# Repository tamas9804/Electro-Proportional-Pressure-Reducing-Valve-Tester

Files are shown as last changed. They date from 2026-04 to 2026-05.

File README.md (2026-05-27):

# Elektronikus nyomáscsökkentő szelep tesztelő

## Megvalósítandó funkciók

### 1. Mérési funkciók 
* **Szelepek folytonosságának mérése:** Gyors szakadás- és zárlatvizsgálat a szelepek tekercsén.
* **Nagy pontosságú ellenállásmérés:** A szelepek tekercsellenállásának precíziós mérése **0,1%-os pontossággal**, ami lehetővé teszi a minimális menetzárlatok vagy degradációk kiszűrését is.
* **Többcsatornás architektúra:** A rendszernek alkalmasnak kell lennie egyszerre két szelep fogadására és mérésére/tesztelésére.

### 2. Vezérlési és hajtás funkciók 
* **Teljes kivezérlés:** A szelepek direkt, folyamatos (100%-os) kivezérlése a maximális elmozdulás és működés ellenőrzéséhez.
* **PWM kivezérlés:** Impulzusszélesség-modulált (PWM) jel biztosítása a proporcionális szelepek áram- és nyomásszabályzási karakterisztikájának teszteléséhez.
* **Polaritásváltás (H-híd konfiguráció):** A hardvernek felkészültnek kell lennie a polaritás szoftveres felcserélésére, biztosítva a jövőbeli kompatibilitást a többállású vagy irányváltó szelepekkel.

### 3. Hardver és elektromos védelem 
* **Széles tápfeszültség-tartomány:** Az áramkörnek stabilan kell üzemelnie **12V és 24V DC** közötti betáplálási feszültségen, alkalmazkodva az ipari és járműipari szabványokhoz.
* **Fordított polaritás elleni védelem:** Védelem a tápvezetékek téves felcserélése ellen a belső elektronika megóvása érdekében.
* **Túláramvédelem:** A fő tápágat egy **10A-es biztosíték** védi a zárlatokból vagy túlterhelésekből adódó károk ellen.

### 4. Felhasználói felület és szoftver 
* **Beépített menürendszer:** A műszernek rendelkeznie kell egy lokális kijelzőn és fizikai nyomógombokon keresztül kezelhető, jól strukturált menürendszerrel. A szoftvernek kötelezően biztosítania kell az alábbi dedikált menüpontokat:
  * **Teljes teszt:** Egy automatizált tesztszekvencia, amely felhasználói beavatkozás nélkül, egymás után elvégzi a szakadásvizsgálatot, az ellenállásmérést, és végül teljesen kivezérli a szelepet.
  * **Szakadásvizsgálat:** Külön menüpont a tekercs folytonosságának gyors és célzott ellenőrzésére.
  * **Ellenállásmérés:** Dedikált funkció a szelep tekercsellenállásának precíziós mérésére.
  * **Teljes kivezérlés:** A szelep 100%-os, folyamatos statikus meghajtása az azonnali működés-ellenőrzéshez.
  * **PWM kivezérlés:** Impulzusszélesség-modulált (PWM) jel kiadása a szelep proporcionális mozgásának teszteléséhez.
  * **Beállítások:** Rendszerkonfigurációs menü, ahol a felhasználó megadhatja a tesztelt szelepek számát, illetve kiválaszthatja a kívánt nyelvet.
* **Többnyelvűség:** A szoftver képesnek kell lennie több nyelv (Magyar, Angol, Német) dinamikus kezelésére és tartós tárolására.A műszernek újraindítás után is megkell jegyeznie az elmentett szelepek számát, illetve a beállított nyelvet

##  Kiválasztott hardverkomponensek 

A projekt áramköri kialakítása során a fő szempont a megbízhatóság, a költséghatékonyság, valamint az ipari (12-24V) környezetnek való megfelelés volt. Az áramkör az alábbi főbb alkatrészekre épül:

### 1 Vezérlés és Megjelenítés
* **Arduino Nano (ATmega328P):** Költséghatékony, könnyen programozható, és az I/O lábszáma, valamint a számítási kapacitása tökéletesen elegendő a műszer funkcióinak (állapotgép, I2C kommunikáció, PWM) ellátására.
* **16x4 LCD kijelző (I2C modullal):** A teszteredmények és a menürendszer megjelenítéséért felel. Az I2C bővítőnek köszönhetően mindössze két adatvonalat (SDA, SCL) igényel, így rengeteg portot spórol meg a mikrokontrolleren, és a programozása is rendkívül egyszerű.
### 2 Precíziós Mérésadatgyűjtés
* **ADS1115 (16-bites ADC):** A mikrokontroller beépített, alacsonyabb felbontású analóg-digitális átalakítója helyett ez a dedikált IC garantálja a rendkívül pontos (akár 0,1%-os) áram- és feszültségmérést.
* **LM317 feszültségszabályzó (Áramgenerátoros módban):** A precíziós ellenállásmérés alapja. Stabil, állandó mérőáramot biztosít a szelepek tekercsére, ami elengedhetetlen a pontos ellenállás kiszámításához.
* **Feszültségosztó hálózat:** Egy dedikált, egyszerű és gyors mérőáramkör a tekercsek folytonosságának azonnali ellenőrzésére.
### 3. Teljesítményvezérlés és Tápellátás
* **LM2596S DC-DC Step-down konverter:** A műszer tápegysége. A széles ipari feszültségtartományt (12V - 24V) hatékonyan és biztonságosan alakítja át a logikai áramkörök számára szükséges 5V-os stabil feszültségre.
* **AOD409 (P-csat) és IRLR2705 (N-csat) MOSFET-ek:** Ezek a nagy áramtűrésű tranzisztorok felelnek a szelepek (H-híd topológiájú) meghajtásáért. Biztosítják a biztonságos, melegedésmentes PWM szabályozást és a folyamatos, 100%-os kivezérlést a legnagyobb áramfelvételű szelepek esetén is.
* **SRD-05VDC-SL-C 5V Relék:** Mechanikus kapcsolóelemek, amelyek a különböző mérési körök (pl. áramgenerátoros mérés és PWM hajtás) fizikai és galvanikus leválasztását végzik, védve ezzel az érzékeny mérőelektronikát a tesztelés során.
### 4. Mechanika és Csatlakozók
* **JST XH csatlakozók a PCB-n:** A kijelző, a nyomógombok és a potenciométerek nem közvetlenül a panelre vannak forrasztva, hanem szabványos XH csatlakozókkal csatlakoznak. Ez drasztikusan megkönnyíti az alkatrészek cseréjét, valamint sokkal nagyobb szabadságot ad a végleges műszerház (enclosure) 3D tervezésénél és összeszerelésénél

## Részletes Áramköri Felépítés

Mivel a teljes kapcsolási rajz A3-as méretű, a könnyebb átláthatóság és olvashatóság érdekében funkcionális blokkokra bontva mutatjuk be a hardver működését.

A teljes rajz letölthető [**PDF formátumban**](Hardware/EPPR_tester_full.pdf)

### 1. Tápellátás és Fordított Polaritás Elleni Védelem
Ez a modul felel a rendszer stabil feszültségellátásáért. A 24V-os bemenetet egy biztosíték és egy dióda védi a fordított polaritás ellen. Egy **LM2596S** kapcsolóüzemű szabályzó állítja elő a logikai áramkörök számára szükséges stabil 5V-ot nagy hatásfokkal.

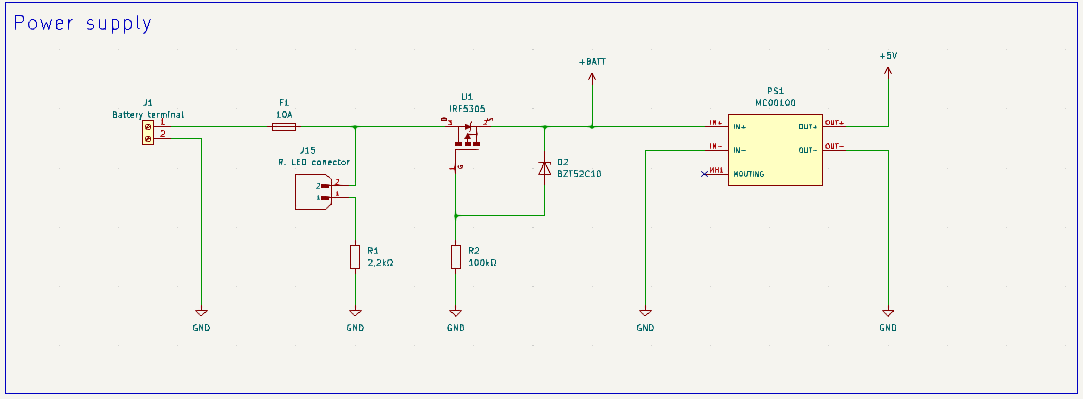
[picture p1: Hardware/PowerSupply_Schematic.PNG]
Tápellátás


### 2. Vezérlő interfészek és Felhasználói Felület csatlakozók
Itt látható az **Arduino Nano** mikrokontroller központi bekötése. Ez a modul kezeli az I2C buszt az LCD kijelzőt és az ADC-t. Tartalmazza a JST XH csatlakozók bekötését a navigációs nyomógombokhoz, a potméterhez.

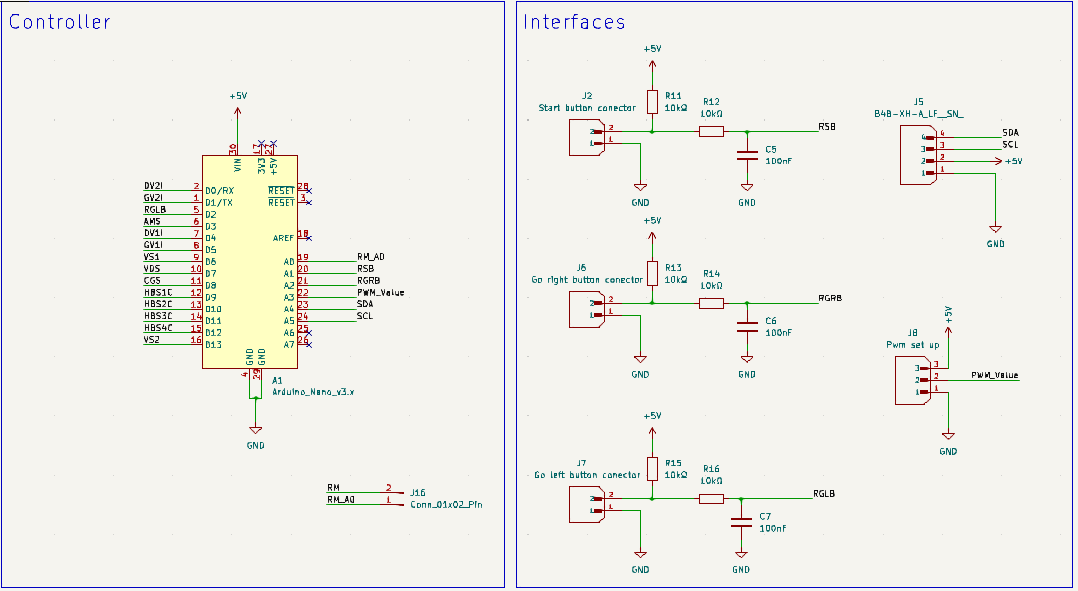
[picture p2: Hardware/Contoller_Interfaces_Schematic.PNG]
Vezérlő


#### 3. Precíziós Analóg-Digitális Átalakítás 
A nagy pontosságú mérésekért egy **ADS1115** 16-bites külső ADC modul felel. I2C buszon kommunikál a vezérlővel.

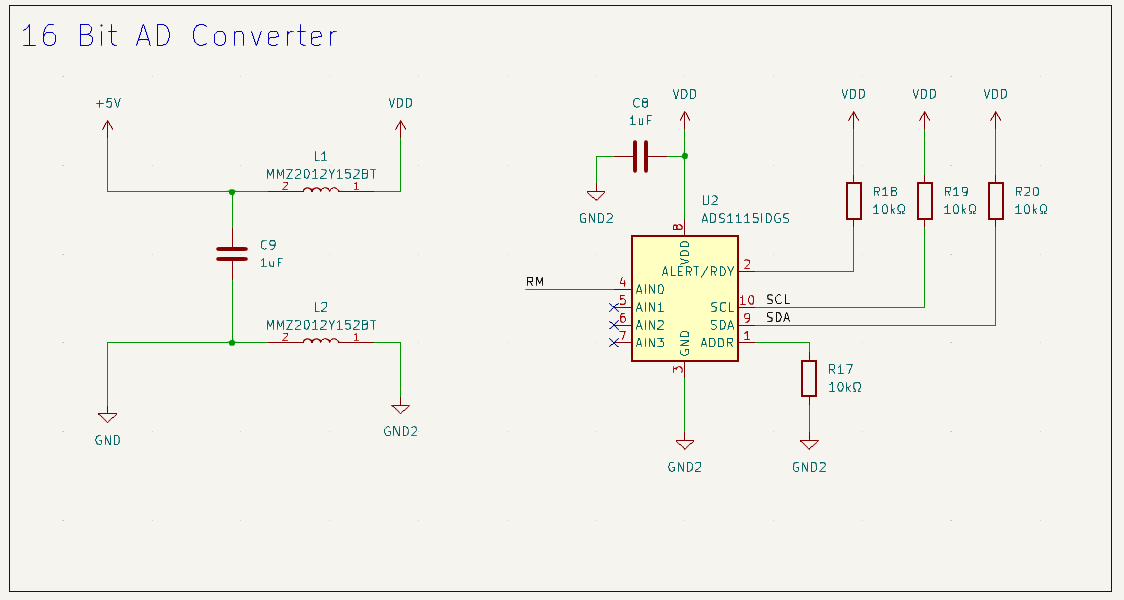
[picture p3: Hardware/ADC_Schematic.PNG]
ADC modul


### 4 Polaritás váltó híd 
Ez az áramkör tartalmazza a polaritás váltást az adott kimeneten, illetve kezeli hogy 12V illetve 24V-ről is tudjon működni.

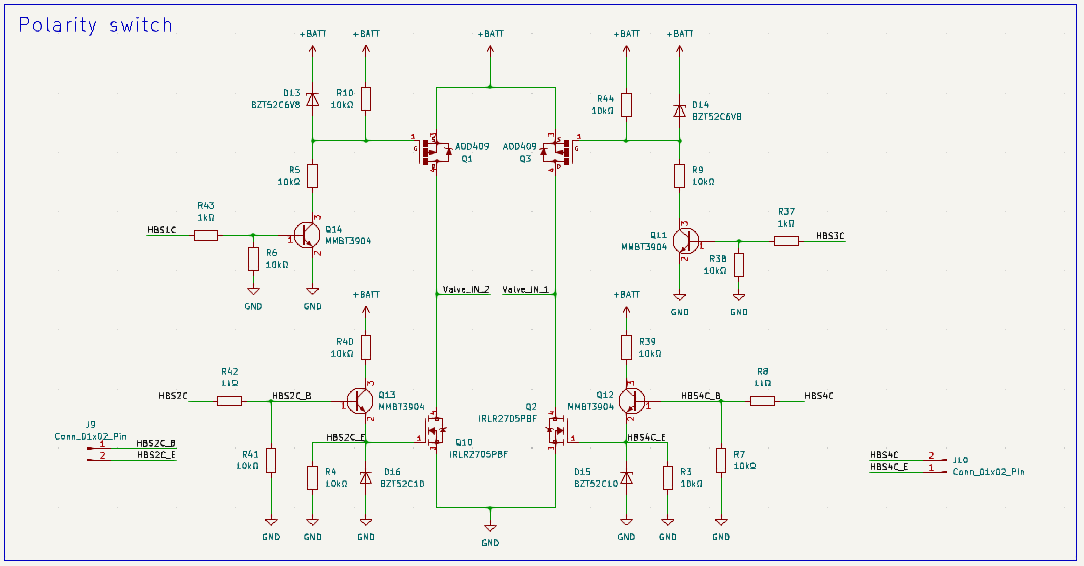
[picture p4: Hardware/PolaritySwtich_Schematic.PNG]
Funkcióváltó


### 5 Mérési Mód Választó Relé 
Ez a modul választja ki, hogy az ADC éppen az analóg mérőjelet vagy a folytonossági teszthez szükséges feszültségosztót olvassa be.

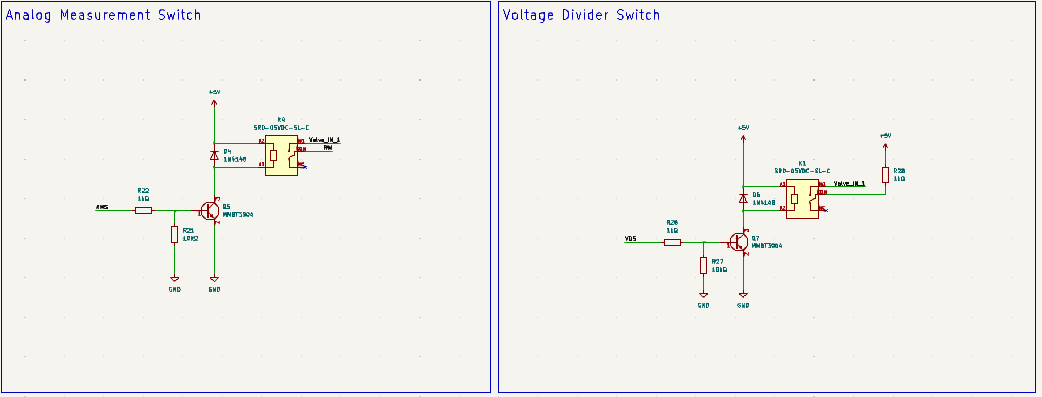
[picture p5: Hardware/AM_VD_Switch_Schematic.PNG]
Mérési mód választó


### 6 Szelep Szekvencia Választó Relék
Ez a rész kapcsolja a kimenetet, ezzel a kapcsolással egyszerre két szelep is rácsatlakoztatható és külön külön lemérhető.

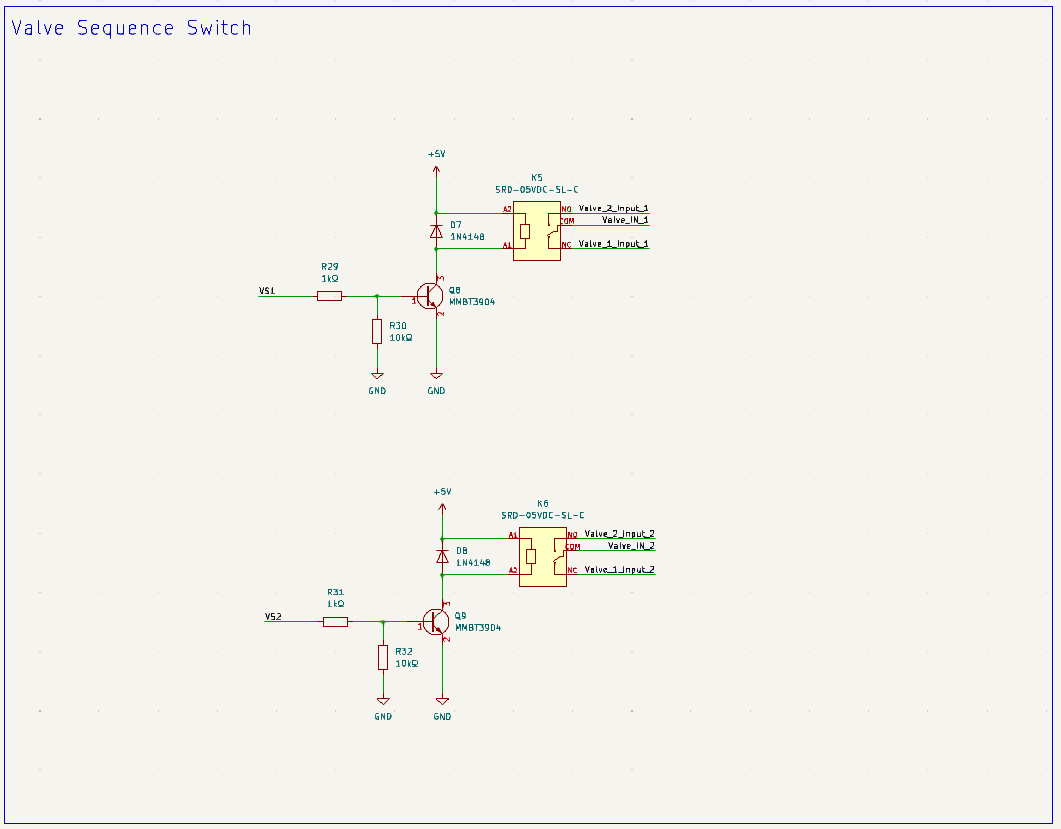
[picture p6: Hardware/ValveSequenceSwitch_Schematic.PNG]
Szelep választó


### 7 Szelep Csatlakozók és Állapotjelző LED-ek
Ez a kimeneti modul tartalmazza a fizikai sorkapcsokat a szelepek bekötéséhez. Tartalmazza az optikai visszajelzést biztosító LED csatlakozását amelyek mutatják az adott szelep kimenet állapotát.

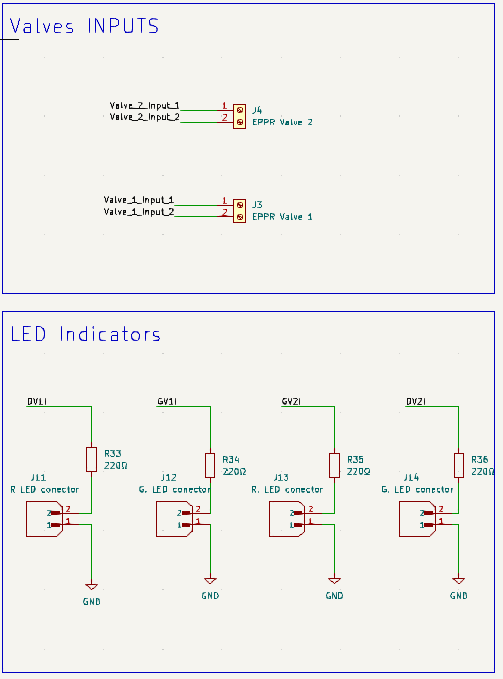
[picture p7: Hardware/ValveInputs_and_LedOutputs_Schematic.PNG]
Szelep kimenetek


## Nyomtatott Áramkör 

A megbízható és zajmentes ipari működés érdekében a NYÁK-tervezés során az alábbi tervezési irányelveket követtem:

* **4 rétegű felépítés:** A panel ipari szabványú **FR-4**-es hordozóanyagra készült, 4 rétegű kialakítással. Ez lehetővé tette a jelvezetékek és a tápvezetékek optimális szétválasztását.
* **Dedikált Föld és Táp síkok:** A kiváló zajvédelem érdekében a két belső réteg dedikált feladatot kapott. Az egyik egy megszakítás nélküli, masszív Föld-sík, a másik pedig egy egybefüggő Táp-sík (5V). Ez minimalizálja a hurok-induktivitást és stabil referenciát biztosít a precíziós analóg mérésekhez.
* **Áramra méretezett vezetősávok:** A teljesítményelektronikai részeknél a vezetősávok szélessége a maximális átfolyó áramra lett méretezve a melegedés és a feszültségesés elkerülése végett.
* **Zajszűrés optimalizálása:** A tápszűrő kondenzátorok fizikailag a lehető legközelebb kerültek az integrált áramkörök (Arduino Nano, ADS1115, LM317) táplábaihoz, így hatékonyan nyelik el a magas frekvenciás tranzienseket.
* **Adatvonalak árnyékolása:** A kritikus kommunikációs vonalak (például az I2C busz SDA és SCL vonalai) a rézrétegen mindkét oldalról föld-sávokkal lettek körbevéve. Ez a technika drasztikusan csökkenti az áthallást és megvédi az érzékeny digitális jeleket a relék által keltett zavaroktól.
* **Precíziós Analóg Tápszűrés:** Az **ADS1115** 16-bites ADC tápellátását egy dedikált ferrit szűrővel választottuk le a közös 5V-os digitális tápvezetékről. Ez a szűrőmegoldás hatékonyan blokkolja a mikrokontroller és a digitális kapcsolóelemek által keltett nagyfrekvenciás zajokat, így garantálja a zajmentes tápfeszültséget az ADC számára, ami elengedhetetlen a 0,1%-os mérési pontosság eléréséhez.

## 3D Modell

A nyomtatott áramkörről és a rászerelt alkatrészekről egy teljes 3D modell készült. Ez a modell alapvető fontosságú a műszer külső dobozolásának megtervezéséhez, az ütközések ellenőrzéséhez, valamint a gombok és a kijelző pontos pozicionálásához.

**A PCB 3D-s látványterve :**
[**Kattints ide a panel interaktív 3D megtekintéséhez!**](Hardware/3D%20file/EPPR%20tester.stl)

## Fizikai Összeépítés és Prototípus

Az alábbi képen a már legyártott, 4 rétegű **FR-4**-es nyomtatott áramkör látható a valóságban, készre szerelt állapotban. 

**A kész, működőképes áramkör a valóságban:**
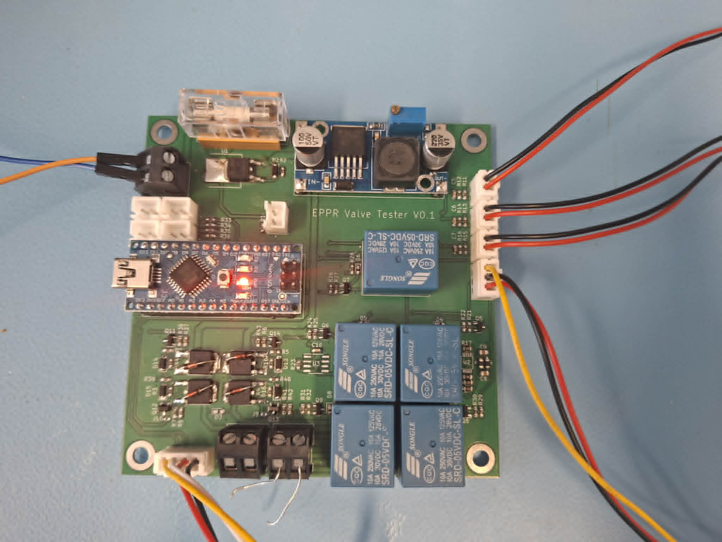
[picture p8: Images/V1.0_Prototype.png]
Fizikai összeépítés


## Szoftver Architektúra és Kódolási Irányelvek 

A beágyazott szoftver **C++ nyelven**, az Arduino keretrendszerre támaszkodva íródott. A kódolás során a fő szempont a megbízhatóság, a mikrokontroller szűkös erőforrásainak optimalizálása, valamint a méréstechnikai pontosság maximalizálása volt.

A fejlesztés során az alábbi kulcsfontosságú programozási technikákat alkalmaztuk:

### 1. Véges Állapotgép 
A szoftver működése egy robusztus, többszintű állapotgépre épül. Az állapotokat (Főmenü, Beállítások, Tesztelési folyamatok) `enum class` struktúrák vezérlik (`SystemMode`, `MenuStates`, `SettingStates`).
* **Előny:** Ez a megközelítés teljesen kiküszöböli az átláthatatlan kódot, és a `loop()` függvényt könnyen bővíthetővé teszi, elkerülve a blokkoló várakozásokat.

### 2. Memóriaoptimalizálás és Többnyelvűség
A műszer három nyelvet támogat (Magyar, Angol, Német). Mivel a kijelzőn megjelenő stringek gyorsan kimerítenék az Arduino Nano (ATmega328P) mindössze 2 kByte-os SRAM memóriáját, az összes szöveges konstans a **Flash memóriában (`PROGMEM`)** kapott helyet.
* **Megvalósítás:** Egy dedikált lekérdező függvény (`getText()`) olvassa ki a kért nyelvi elemeket futásidőben a Flash memóriából egy rövid bufferbe, drasztikusan csökkentve a futásidejű memóriafoglalást.

#### 3. Szoftveres Zajszűrés és Dinamikus Felbontás
A 0,1%-os pontosságú mérés érdekében a hardveres szűrés mellett speciális szoftveres eljárásokat is bevezettem:
* **Túlmintavételezés:** Az analóg értékek beolvasásakor a kód ciklusonként 100 mintát vesz, és ezek átlagolásával (`getAveragedVoltage()`) szűri ki a hálózati és kapcsolási zajokat.
* **Dinamikus Erősítés:** Az ellenállásmérés (`OhmTest`) során a szoftver az ADS1115-ös IC beépített programozható erősítőjét (PGA) dinamikusan állítja (`GAIN_EIGHT`, `GAIN_FOUR`, stb.). Ha a mért feszültség túl alacsony, a rendszer automatikusan nagyobb erősítésre kapcsol, így mindig kihasználja a 16-bites felbontás maximumát a különböző ellenállás-tartományokban.

#### 4. EEPROM Kezelés és "First Start" Detektálás
A felhasználói beállítások (kiválasztott nyelv, szelepek száma) a nem felejtő **EEPROM** memóriában tárolódnak.
* **Intelligens inicializálás:** A szoftver tartalmaz egy `doFirstStart()` logikát, amely egy specifikus azonosító (Magic Number: `78`) keresésével megállapítja, hogy a mikrokontroller most lett-e először felprogramozva. Ha igen, automatikusan feltölti az EEPROM-ot az alapértelmezett gyári értékekkel, megelőzve a memóriaszemétből adódó összeomlásokat.

#### 5. Hardveres Védelem és Tiszta Újraindítás
* A tesztelési fázisok indításakor és leállításakor a szoftver szigorú sorrendben kapcsolja a hardveres reléket és a PWM jeleket, hogy elkerülje a mérőáramkör túlterhelését.
* A beállítások mentése után a rendszer nem szoftveres trükkökkel, hanem a hardveres **Watchdog Timer (`wdt_enable`)** szándékos lejáratásával (`softwareReset()`) hajt végre egy teljesen tiszta újraindítást, garantálva, hogy minden regiszter és memóriacím az alapállapotba kerüljön.

## Javítási és Továbbfejlesztési Tervek 

Bár a műszer prototípusa teljesen működőképes és ellátja az alapvető mérési funkciókat, a jövőbeli verziókhoz az alábbi javítások lehetőségesek:

### Szoftveres javítások és optimalizálás (Known Issues & Fixes)
* **PWM Teszt implementálása:** A menürendszerben már szerepel, de a `PwmTest()` funkció logikája (a hardveres időzítők és a kitöltési tényező dinamikus állítása) még megírásra vár.
* **Blokkoló kódok kiváltása:** A tesztelési folyamatok végén jelenleg `delay(4000)` található. Ezt a jövőben `millis()` alapú, nem blokkoló időzítésre cseréljük, hogy a műszer közben reagálhasson a gombnyomásokra.
* **Kalibrációs menü:** Egy rejtett menüpont létrehozása, ahol az áramgenerátor és a feszültségosztó pontatlanságait szoftveresen (Offset és Gain értékekkel) lehet kalibrálni és az EEPROM-ba menteni.

### Hardveres és Rendszerszintű továbbfejlesztések
* **Induktív visszarúgás elleni védelem:** A jelenlegi V1.0-s nyomtatott áramkörről lemaradtak a szelepek (induktív terhelések) kikapcsolásakor keletkező feszültségtüskék elleni védődiódák. A működő prototípuson ezt ideiglenesen utólagos ráforrasztással oldottuk meg. A következő PCB terv frissítésnél ezek a Schottky védődiódák dedikált helyet és megfelelő hűtőfelületet kapnak a H-híd kimeneteinél, garantálva a MOSFET-ek hosszú távú védelmét.
* **Adatnaplózás (Data Logging):** Egy MicroSD kártya modul integrálása az I2C/SPI buszra, hogy a teszteredményeket .CSV formátumban el lehessen menteni a későbbi elemzéshez.
* **PC-s kommunikáció (Serial Plotter):** A tesztelés alatti áram- és feszültséggörbék (különösen a PWM kivezérlés esetén) folyamatos küldése USB-n keresztül egy PC-s szoftvernek, vizuális grafikonrajzolás céljából.

### Karbantartás és Fizikai javítás 
A hardver úgy lett megtervezve, hogy a terepi javítás a lehető legegyszerűbb legyen:
* **Relék és Csatlakozók:** A mechanikus kopásnak kitett alkatrészek (SRD relék), egy esetleges beégés esetén könnyen kicseréhetővé tétele

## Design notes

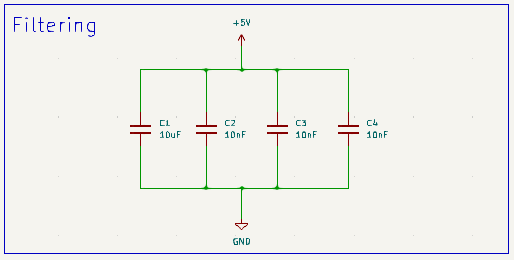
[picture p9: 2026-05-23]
Hardware/Filtering_Schematic.PNG

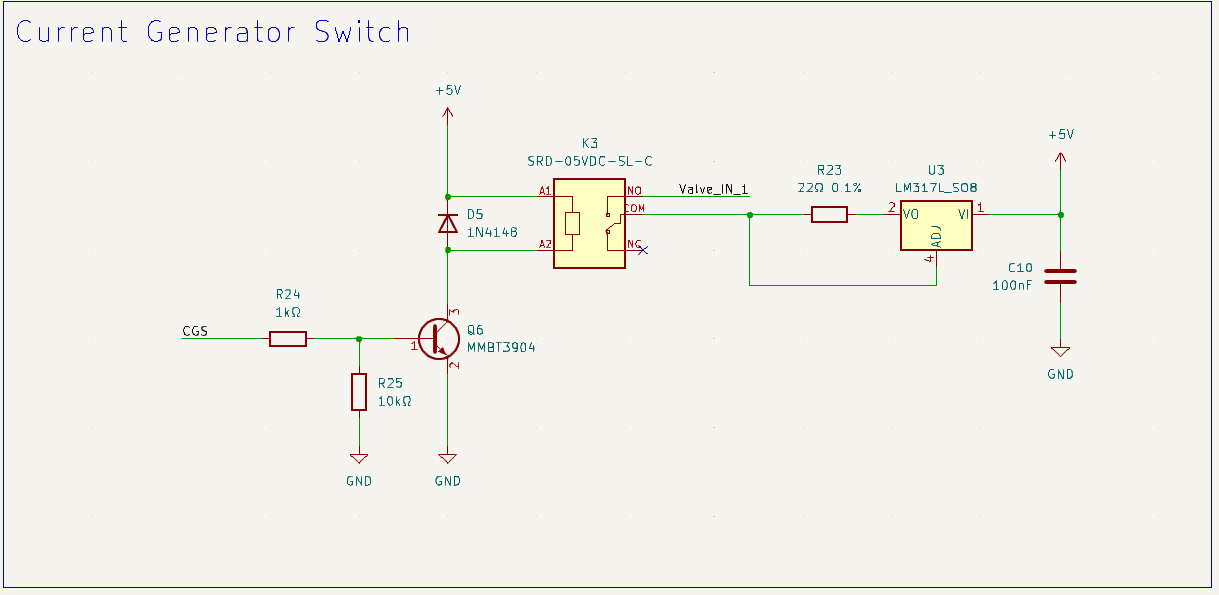
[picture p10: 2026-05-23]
Hardware/CurrentGenerator_Schematic.PNG

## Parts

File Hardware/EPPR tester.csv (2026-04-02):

Column1 | Column2 | Column3 | Column4 | Column5 | Column6 | Column7 | Column8 | Column9 | Column10 | Column11 | Column12 | Column13 | Column14 | Column15 | Column16 | Column17 | Column18 | Column19 | Column20 | Column21 | Column22 | Column23 | Column24 | Column25 | Column26 | Column27 | Column28
Source: | C:\Users\molnart1\Desktop\Vezérlő projekt\EPPR tester\EPPR tester\EPPR tester.kicad_sch
Date: | 2026. 03. 27. 14:00:19
Tool: | Eeschema 7.0.9
Generator: | C:\Program Files\KiCad\7.0\bin\scripting\plugins/bom_csv_grouped_by_value.py
Component Count: | 107
Collated Components:
Item | Qty | Reference(s) | Value | LibPart | Footprint | Datasheet | DNP | Availability | CREATOR | Check_prices | Description | MANUFACTURER | MAXIMUM_PACKAGE_HEIGHT | MF | MP | Manufacturer_Name | Manufacturer_Part_Number | PARTREV | Package | Price | SMD/THT | STANDARD | Sim.Device | Sim.Pins | SnapEDA_Link | Third Party Seller 1 | Website
1 | 1 | A1 | Arduino_Nano_v3.x | MCU_Module:Arduino_Nano_v3.x | Module:Arduino_Nano | http://www.mouser.com/pdfdocs/Gravitech_Arduino_Nano3_0.pdf
2 | 1 | C1 | 10uF | Device:C | Capacitor_SMD:C_1210_3225Metric_Pad1.33x2.70mm_HandSolder | ~
3 | 3 | C2, C3, C4 | 10nF | Device:C | Capacitor_SMD:C_0603_1608Metric_Pad1.08x0.95mm_HandSolder | ~
4 | 4 | C5, C6, C7, C10 | 100nF | Device:C | Capacitor_SMD:C_0603_1608Metric_Pad1.08x0.95mm_HandSolder | ~
5 | 2 | C8, C9 | 1uF | Device:C | Capacitor_SMD:C_0603_1608Metric_Pad1.08x0.95mm_HandSolder | ~
6 | 3 | D2, D15, D16 | BZT52C10 | Device:D_Zener | Diode_SMD:Nexperia_CFP3_SOD-123W | ~
7 | 6 | D3, D4, D5, D6, D7, D8 | 1N4148 | Diode:1N4148 | Diode_SMD:D_0603_1608Metric_Pad1.05x0.95mm_HandSolder | https://www.tme.eu/Document/8a0f4bd1d0e0495ebb1834ba060fbfa0/CD4148.pdf |  |  |  |  |  |  |  |  |  | DC COMPONENTS | CD4148WT(0603C) |  | 0603 |  | SMD |  | D | 1=K 2=A |  | https://www.tme.eu/hu/details/1n4148-0603/univerzalis-smd-diodak/dc-components/cd4148wt-0603c/ | -
8 | 2 | D13, D14 | BZT52C6V8 | Device:D_Zener | Diode_SMD:Nexperia_CFP3_SOD-123W | ~
9 | 1 | F1 | 15A | Device:Fuse | Fuse:Fuseholder_Littelfuse_100_series_5x20mm | ~
10 | 1 | J1 | Battery terminal | Connector:Screw_Terminal_01x02 | TerminalBlock:TerminalBlock_Altech_AK300-2_P5.00mm | ~
11 | 1 | J2 | Start button conector | B2B-XH-A:B2B-XH-A | B2B-XH-A:JST_B2B-XH-A |  |  | In Stock |  | https://www.snapeda.com/parts/B2B-XH-A/JST/view-part/?ref=eda | Connector Header Through Hole 2 position 0.098 (2.50mm) | JST Sales America Inc. | 7 mm | JST Sales | B2B-XH-A |  |  | N/A | None | None |  | Manufacturer Recommendations |  |  | https://www.snapeda.com/parts/B2B-XH-A/JST/view-part/?ref=snap
12 | 1 | J3 | EPPR Valve 1 | Connector:Screw_Terminal_01x02 | TerminalBlock:TerminalBlock_Altech_AK300-2_P5.00mm | ~
13 | 1 | J4 | EPPR Valve 2 | Connector:Screw_Terminal_01x02 | TerminalBlock:TerminalBlock_Altech_AK300-2_P5.00mm | ~
14 | 1 | J5 | B4B-XH-A_LF__SN_ | B4B-XH-A_LF__SN_:B4B-XH-A_LF__SN_ | B4B-XH-A:JST_B4B-XH-A_LF__SN_ |  |  | In Stock |  | https://www.snapeda.com/parts/B4B-XH-A%20(LF)(SN)/JST/view-part/?ref=eda | Connector Header Through Hole 4 position 0.098 (2.50mm) | JST | 7.00 mm | JST Sales | B4B-XH-A (LF)(SN) |  |  | 7/4/21 | None | None |  | Manufacturer Recommendations |  |  | https://www.snapeda.com/parts/B4B-XH-A%20(LF)(SN)/JST/view-part/?ref=snap
15 | 1 | J6 | Go right button conector | B2B-XH-A:B2B-XH-A | B2B-XH-A:JST_B2B-XH-A |  |  | In Stock |  | https://www.snapeda.com/parts/B2B-XH-A/JST/view-part/?ref=eda | Connector Header Through Hole 2 position 0.098 (2.50mm) | JST Sales America Inc. | 7 mm | JST Sales | B2B-XH-A |  |  | N/A | None | None |  | Manufacturer Recommendations |  |  | https://www.snapeda.com/parts/B2B-XH-A/JST/view-part/?ref=snap
16 | 1 | J7 | Go left button conector | B2B-XH-A:B2B-XH-A | B2B-XH-A:JST_B2B-XH-A |  |  | In Stock |  | https://www.snapeda.com/parts/B2B-XH-A/JST/view-part/?ref=eda | Connector Header Through Hole 2 position 0.098 (2.50mm) | JST Sales America Inc. | 7 mm | JST Sales | B2B-XH-A |  |  | N/A | None | None |  | Manufacturer Recommendations |  |  | https://www.snapeda.com/parts/B2B-XH-A/JST/view-part/?ref=snap
17 | 1 | J8 | Pwm set up | B3B-XH-A:B3B-XH-A | B3B-XH-A:JST_B3B-XH-A |  |  | In Stock |  | https://www.snapeda.com/parts/B3B-XH-A/JST/view-part/?ref=eda | Connector Header Through Hole 3 position 0.098 (2.50mm) | JST Sales America Inc. | 7.00 mm | JST Sales | B3B-XH-A |  |  | 7/4/21 | None | None |  | Manufacturer Recommendations |  |  | https://www.snapeda.com/parts/B3B-XH-A/JST/view-part/?ref=snap
18 | 3 | J9, J10, J16 | Conn_01x02_Pin | Connector:Conn_01x02_Pin | Resistor_SMD:R_0402_1005Metric | ~
19 | 1 | J11 | R LED conector | B2B-XH-A:B2B-XH-A | B2B-XH-A:JST_B2B-XH-A |  |  | In Stock |  | https://www.snapeda.com/parts/B2B-XH-A/JST/view-part/?ref=eda | Connector Header Through Hole 2 position 0.098 (2.50mm) | JST Sales America Inc. | 7 mm | JST Sales | B2B-XH-A |  |  | N/A | None | None |  | Manufacturer Recommendations |  |  | https://www.snapeda.com/parts/B2B-XH-A/JST/view-part/?ref=snap
20 | 2 | J12, J14 | G. LED conector | B2B-XH-A:B2B-XH-A | B2B-XH-A:JST_B2B-XH-A |  |  | In Stock |  | https://www.snapeda.com/parts/B2B-XH-A/JST/view-part/?ref=eda | Connector Header Through Hole 2 position 0.098 (2.50mm) | JST Sales America Inc. | 7 mm | JST Sales | B2B-XH-A |  |  | N/A | None | None |  | Manufacturer Recommendations |  |  | https://www.snapeda.com/parts/B2B-XH-A/JST/view-part/?ref=snap
21 | 2 | J13, J15 | R. LED conector | B2B-XH-A:B2B-XH-A | B2B-XH-A:JST_B2B-XH-A |  |  | In Stock |  | https://www.snapeda.com/parts/B2B-XH-A/JST/view-part/?ref=eda | Connector Header Through Hole 2 position 0.098 (2.50mm) | JST Sales America Inc. | 7 mm | JST Sales | B2B-XH-A |  |  | N/A | None | None |  | Manufacturer Recommendations |  |  | https://www.snapeda.com/parts/B2B-XH-A/JST/view-part/?ref=snap
22 | 3 | K1, K3, K6 | SRD-05VDC-SL-C | SRD-05VDC-SL-C:SRD-05VDC-SL-C | SRD-05VDC-SL-C:RELAY_SRD-05VDC-SL-C |  |  | In Stock |  | https://www.snapeda.com/parts/SRD-05VDC-SL-C/Songle+Relay/view-part/?ref=eda | 5V Trigger Relay Module For Arduino And Raspberry Pi 5V Trigger Relay Module For Arduino And Raspberry Pi | SONGLE RELAY |  | Songle Relay | SRD-05VDC-SL-C |  |  |  | NON STANDARD-5 Songle Relay | None |  | IPC-7251 |  |  | https://www.snapeda.com/parts/SRD-05VDC-SL-C/Songle+Relay/view-part/?ref=snap
23 | 1 | K4 | SRD-05VDC-SL-C | :SRD-05VDC-SL-C_1 | SRD-05VDC-SL-C:RELAY_SRD-05VDC-SL-C |  |  | In Stock |  | https://www.snapeda.com/parts/SRD-05VDC-SL-C/Songle+Relay/view-part/?ref=eda | 5V Trigger Relay Module For Arduino And Raspberry Pi 5V Trigger Relay Module For Arduino And Raspberry Pi | SONGLE RELAY |  | Songle Relay | SRD-05VDC-SL-C |  |  |  | NON STANDARD-5 Songle Relay | None |  | IPC-7251 |  |  | https://www.snapeda.com/parts/SRD-05VDC-SL-C/Songle+Relay/view-part/?ref=snap
24 | 1 | K5 | SRD-05VDC-SL-C | :SRD-05VDC-SL-C_2 | SRD-05VDC-SL-C:RELAY_SRD-05VDC-SL-C |  |  | In Stock |  | https://www.snapeda.com/parts/SRD-05VDC-SL-C/Songle+Relay/view-part/?ref=eda | 5V Trigger Relay Module For Arduino And Raspberry Pi 5V Trigger Relay Module For Arduino And Raspberry Pi | SONGLE RELAY |  | Songle Relay | SRD-05VDC-SL-C |  |  |  | NON STANDARD-5 Songle Relay | None |  | IPC-7251 |  |  | https://www.snapeda.com/parts/SRD-05VDC-SL-C/Songle+Relay/view-part/?ref=snap
25 | 2 | L1, L2 | MMZ2012Y152BT | MMZ2012Y152BT:MMZ2012Y152BT | MMZ2012Y152B:INDC2012X87N |  |  | In Stock |  | https://www.snapeda.com/parts/MMZ2012Y152B/TDK/view-part/?ref=eda | 1.5 kOhms @ 100 MHz 1 Signal Line Ferrite Bead 0805 (2012 Metric) 500mA 400mOhm |  |  | TDK | MMZ2012Y152B |  |  |  | 0805 TDK | None |  |  |  |  | https://www.snapeda.com/parts/MMZ2012Y152B/TDK/view-part/?ref=snap
26 | 1 | PS1 | MC00100 | MC00100:MC00100 | MC00100:CONV_MC00100 |  |  | Not in stock | ASHISH | https://www.snapeda.com/parts/MC00100/YKS/view-part/?ref=eda | DC-DC LM2596 Step Down Adjustable Converter Power Supply Module 1.3V-35V | YKS | 14.00mm | YKS | MC00100 |  |  | NA | None | None |  | Manufacturer Recommendations |  |  | https://www.snapeda.com/parts/MC00100/YKS/view-part/?ref=snap
27 | 2 | Q1, Q3 | AOD409 | IRFR5505:IRFR5505 | IRF5505:DPAK |  |  | In Stock |  | https://www.snapeda.com/parts/IRFR5505/Infineon/view-part/?ref=eda | P-Channel 55 V 18A (Tc) 57W (Tc) Surface Mount D-Pak |  |  | Infineon Technologies | IRFR5505 |  |  |  | TO-252 Infineon | None |  |  |  |  | https://www.snapeda.com/parts/IRFR5505/Infineon/view-part/?ref=snap
28 | 2 | Q2, Q10 | IRLR2705PBF | IRLR2705PBF:IRLR2705PBF | IRLR2705PBF:TO229P990X239-4N |  |  | In Stock |  | https://www.snapeda.com/parts/IRLR2705PBF/Infineon/view-part/?ref=eda | MOSFET, Power,N-Ch,VDSS 55V,RDS(ON) 0.04Ohm,ID 28A,D-Pak (TO-252AA),PD 68W,-55C | Infineon IRLR2705PBF | Infineon | 2.39 mm | Infineon Technologies | IRLR2705PBF |  |  | 1/11/05 | TO-252 Infineon | None |  | IPC 7351B |  |  | https://www.snapeda.com/parts/IRLR2705PBF/Infineon/view-part/?ref=snap
29 | 9 | Q5, Q6, Q7, Q8, Q9, Q11, Q12, Q13, Q14 | MMBT3904 | Transistor_BJT:MMBT3904 | Package_TO_SOT_SMD:SOT-23 | https://www.onsemi.com/pdf/datasheet/pzt3904-d.pdf
30 | 1 | R1 | 2,2kΩ | Device:R | Resistor_SMD:R_0603_1608Metric_Pad0.98x0.95mm_HandSolder | ~
31 | 1 | R2 | 100kΩ | Device:R | Resistor_SMD:R_0603_1608Metric_Pad0.98x0.95mm_HandSolder | ~
32 | 27 | R3, R4, R5, R6, R7, R9, R10, R11, R12, R13, R14, R15, R16, R17, R18, R19, R20, R21, R25, R27, R30, R32, R38, R39, R40, R41, R44 | 10kΩ | Device:R | Resistor_SMD:R_0603_1608Metric_Pad0.98x0.95mm_HandSolder | ~
33 | 10 | R8, R22, R24, R26, R28, R29, R31, R37, R42, R43 | 1kΩ | Device:R | Resistor_SMD:R_0603_1608Metric_Pad0.98x0.95mm_HandSolder | ~
34 | 1 | R23 | 22Ω 0.1% | Device:R | Resistor_SMD:R_0603_1608Metric_Pad0.98x0.95mm_HandSolder | ~
35 | 4 | R33, R34, R35, R36 | 220Ω | Device:R | Resistor_SMD:R_0603_1608Metric_Pad0.98x0.95mm_HandSolder | ~
36 | 1 | U1 | IRF5305 | IRF5305:IRF5305 | IRF5305:TO263AB |  |  | In Stock |  | https://www.snapeda.com/parts/IRF5305/Infineon/view-part/?ref=eda | P-Channel 55 V 31A (Tc) 3.8W (Ta), 110W (Tc) Surface Mount D2PAK |  |  | Infineon / IR | IRF5305 |  |  |  | TO-220 Infineon | None |  |  |  |  | https://www.snapeda.com/parts/IRF5305/Infineon/view-part/?ref=snap
37 | 1 | U2 | ADS1115IDGS | Analog_ADC:ADS1115IDGS | Package_SO:TSSOP-10_3x3mm_P0.5mm | http://www.ti.com/lit/ds/symlink/ads1113.pdf
38 | 1 | U3 | LM317L_SO8 | Regulator_Linear:LM317L_SO8 | Package_SO:SOIC-8_3.9x4.9mm_P1.27mm | http://www.ti.com/lit/ds/snvs775k/snvs775k.pdf

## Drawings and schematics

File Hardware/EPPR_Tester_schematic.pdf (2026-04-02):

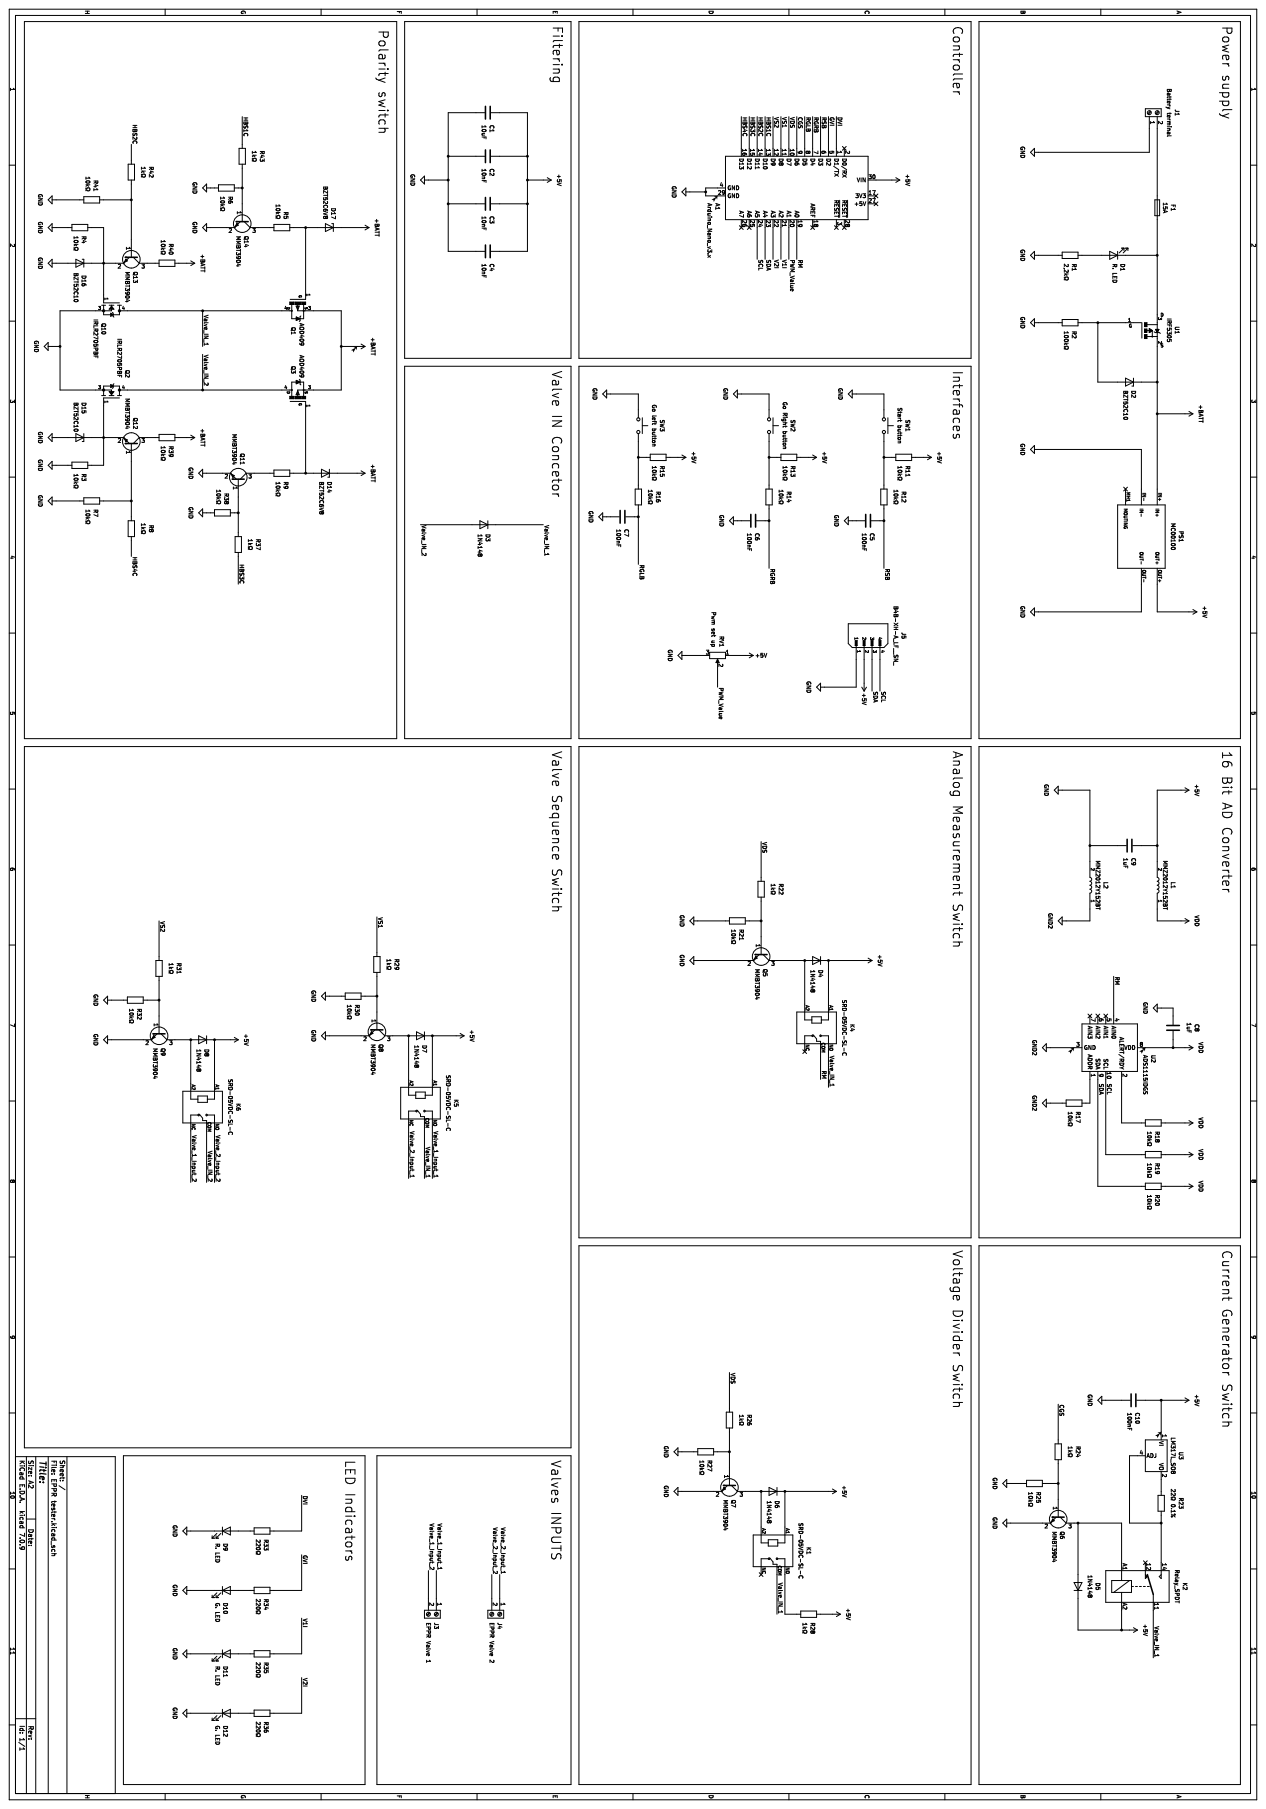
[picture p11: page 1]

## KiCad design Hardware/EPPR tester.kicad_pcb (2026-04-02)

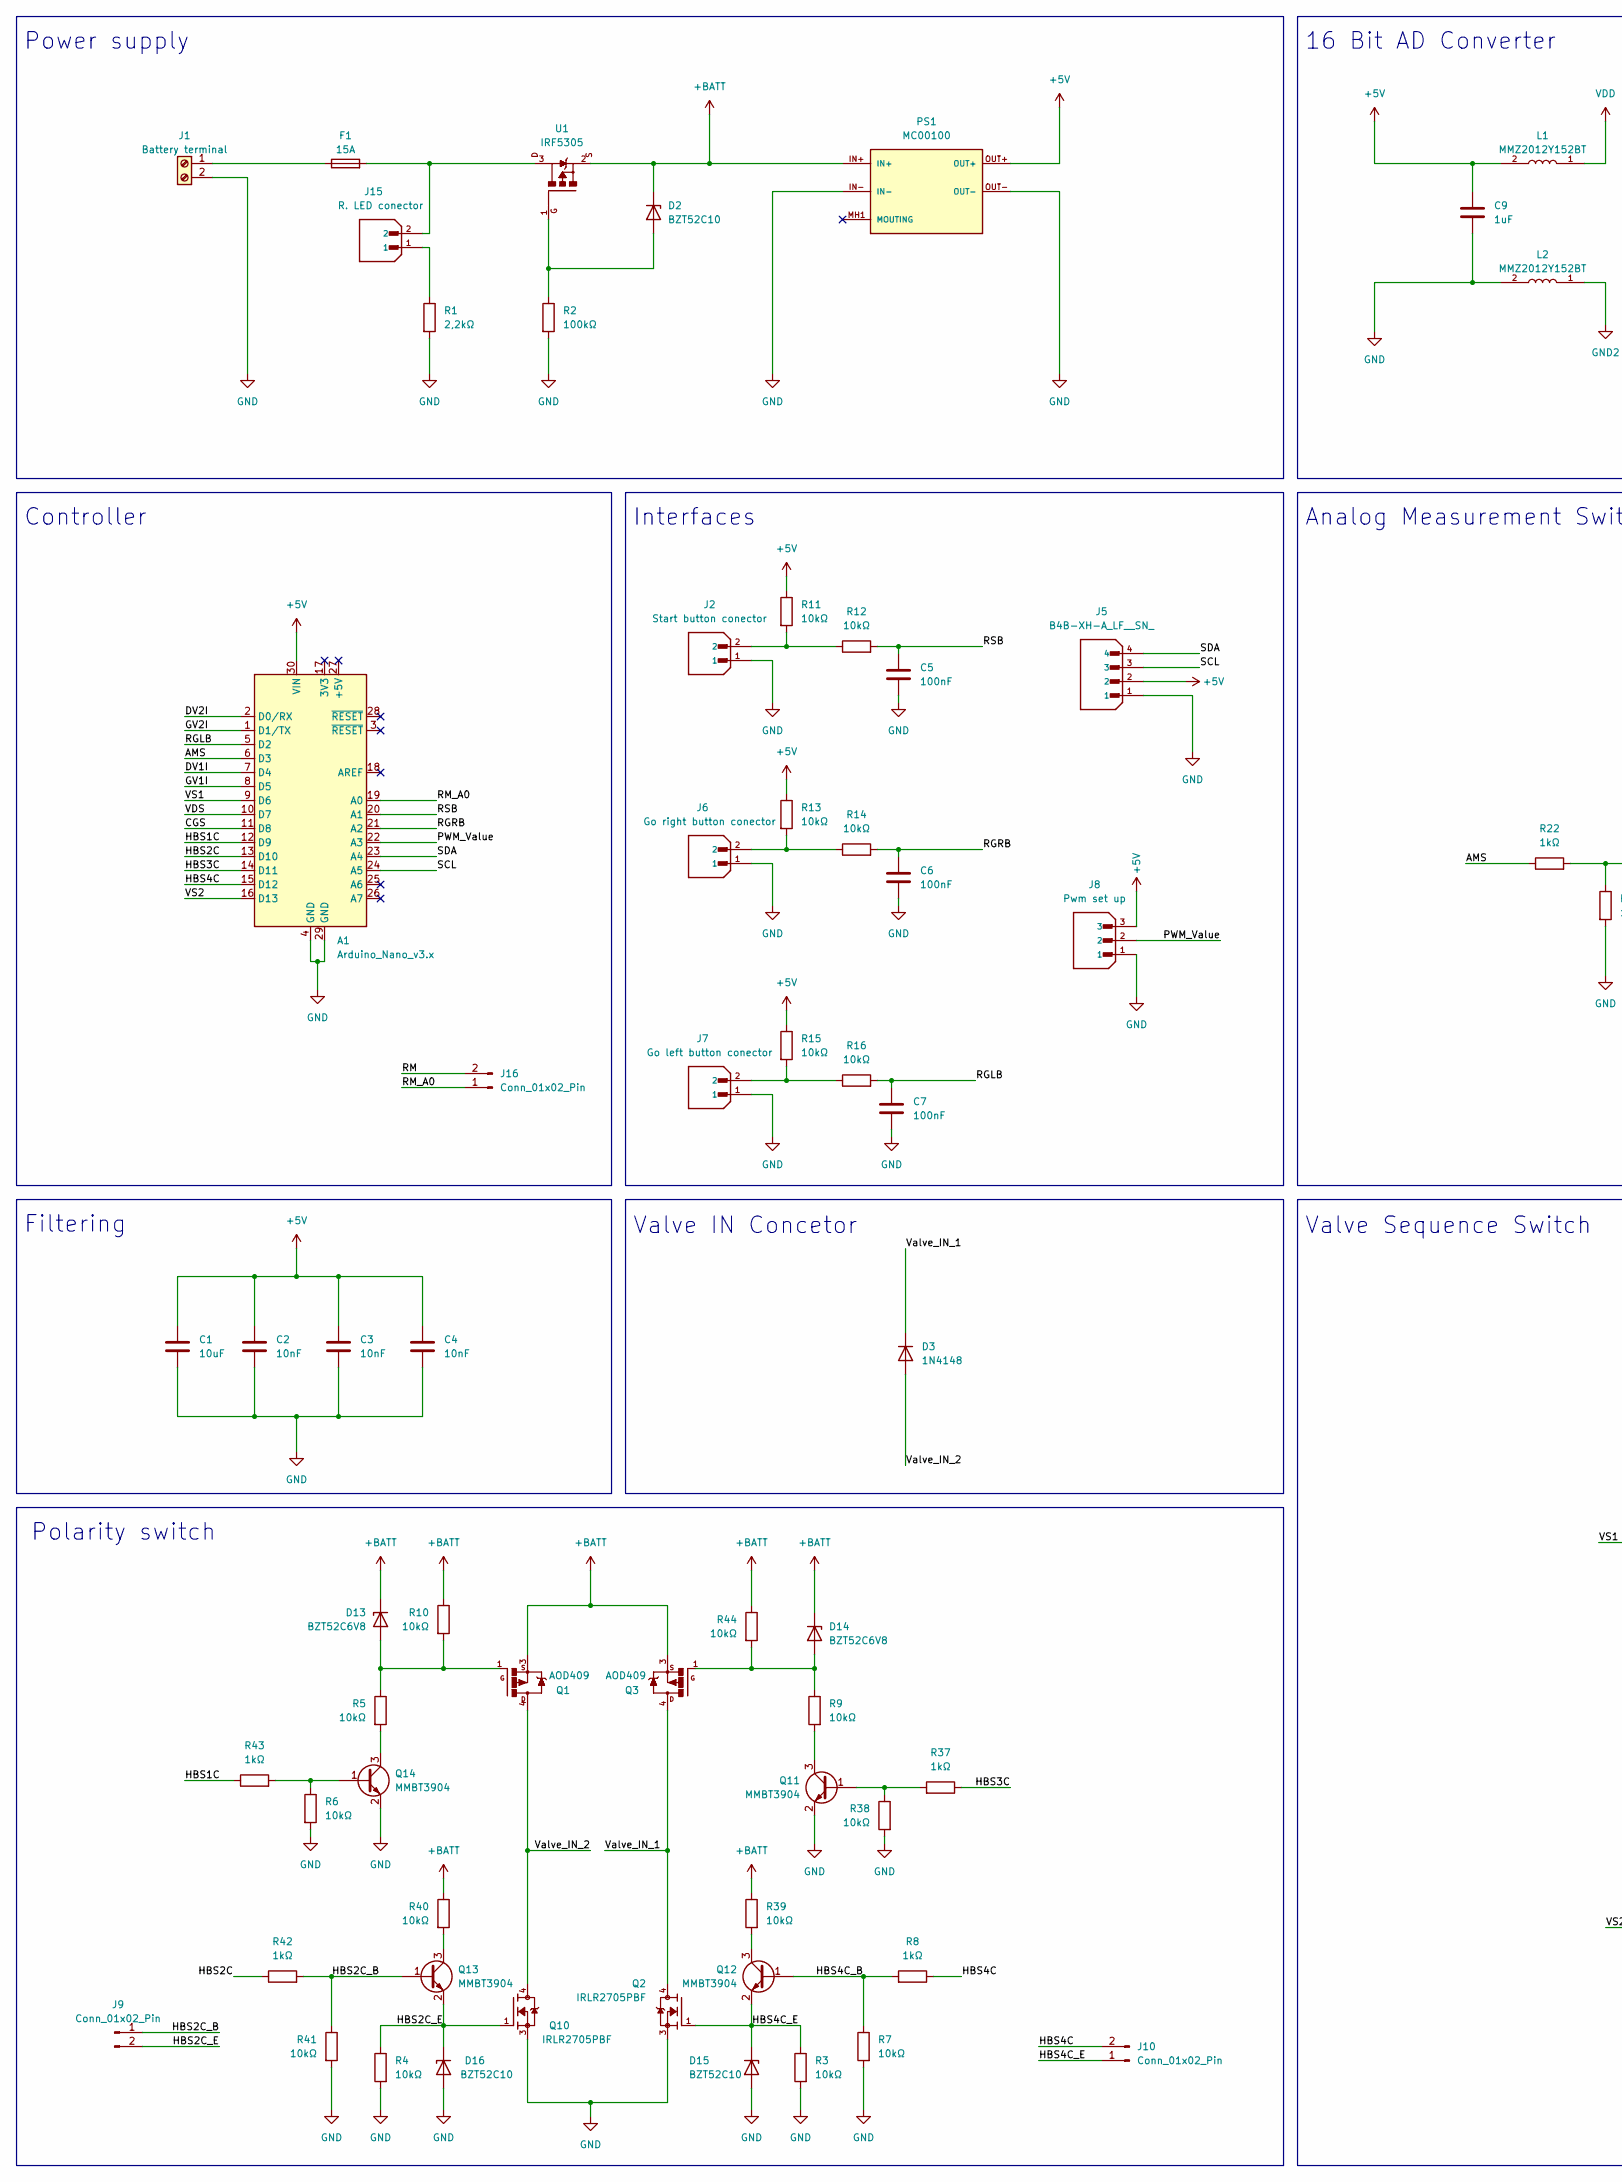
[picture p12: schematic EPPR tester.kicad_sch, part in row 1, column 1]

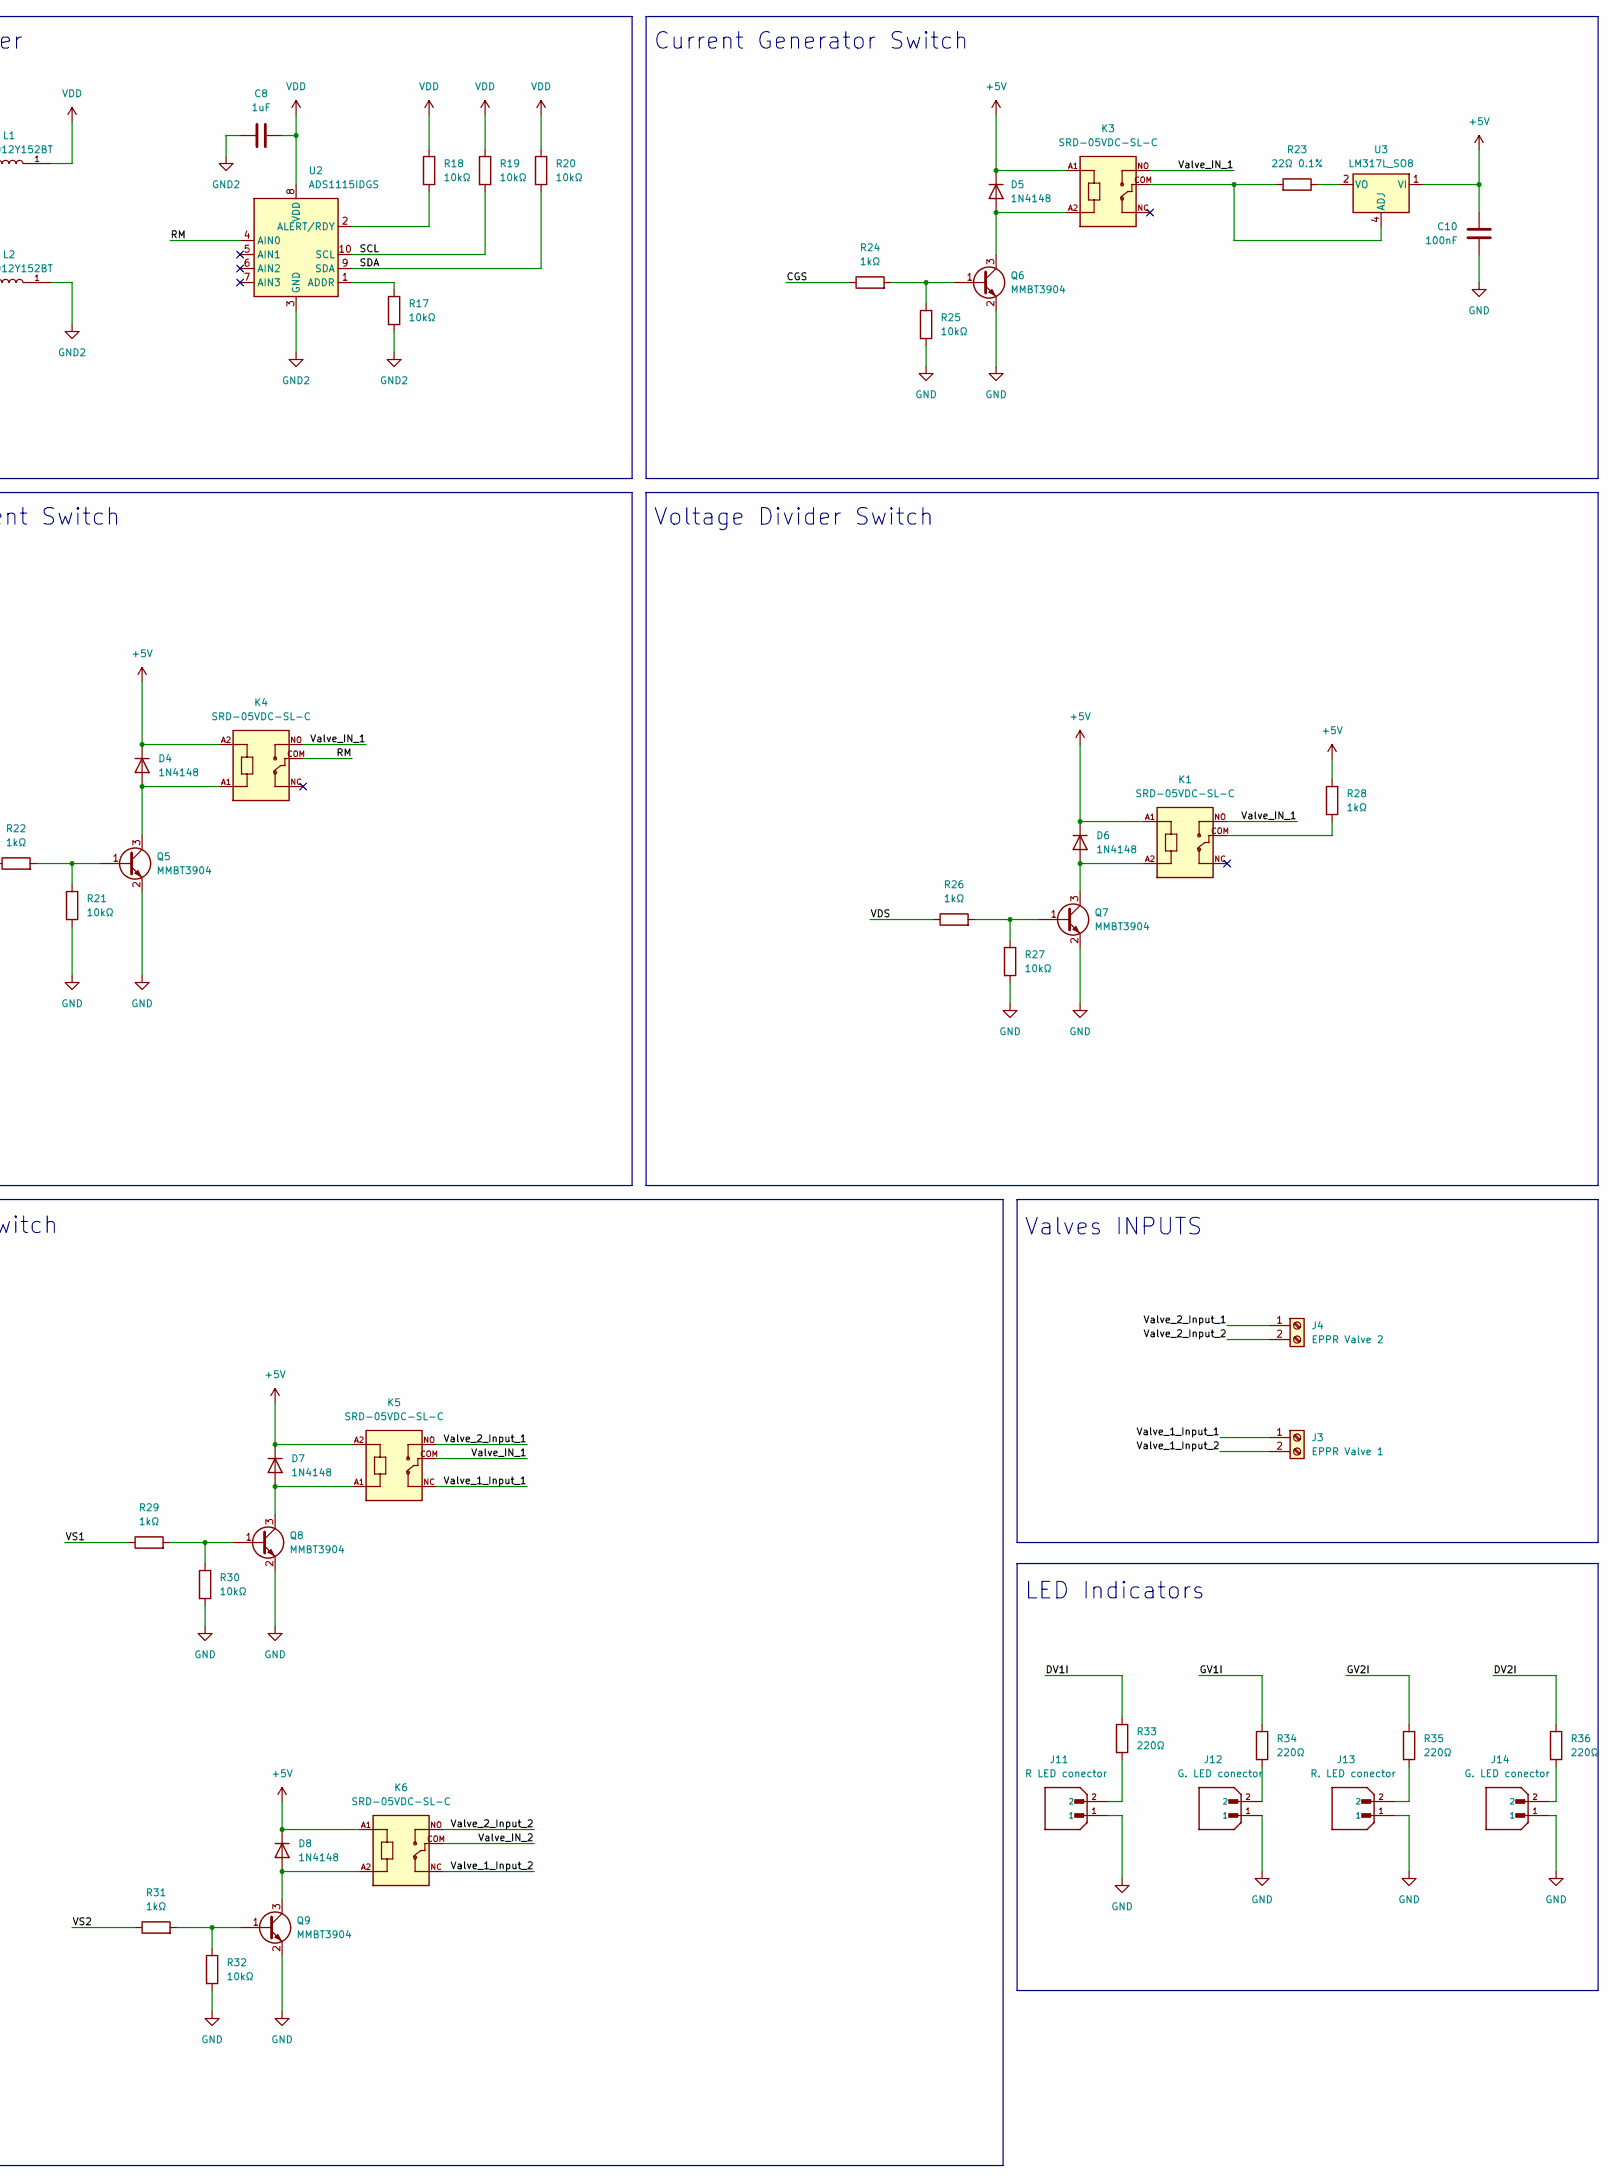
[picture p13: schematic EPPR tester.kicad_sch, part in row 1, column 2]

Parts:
A1: Arduino_Nano_v3.x; Arduino_Nano
C1: 10uF; C_1210_3225Metric_Pad1.33x2.70mm_HandSolder
C2, C3, C4: 10nF; C_0603_1608Metric_Pad1.08x0.95mm_HandSolder
C5, C6, C7, C10: 100nF; C_0603_1608Metric_Pad1.08x0.95mm_HandSolder
C8, C9: 1uF; C_0603_1608Metric_Pad1.08x0.95mm_HandSolder
D2, D15, D16: BZT52C10; Nexperia_CFP3_SOD-123W
D3, D4, D5, D6, D7, D8: 1N4148; D_0603_1608Metric_Pad1.05x0.95mm_HandSolder; Manufacturer_Part_Number CD4148WT(0603C)
D13, D14: BZT52C6V8; Nexperia_CFP3_SOD-123W
F1: 15A; Fuseholder_Littelfuse_100_series_5x20mm
J1: Battery terminal; TerminalBlock_Altech_AK300-2_P5.00mm
J2: Start button conector; JST_B2B-XH-A; PARTREV N/A
J3: EPPR Valve 1; TerminalBlock_Altech_AK300-2_P5.00mm
J4: EPPR Valve 2; TerminalBlock_Altech_AK300-2_P5.00mm
J5: B4B-XH-A_LF__SN_; JST_B4B-XH-A_LF__SN_; PARTREV 7/4/21
J6: Go right button conector; JST_B2B-XH-A; PARTREV N/A
J7: Go left button conector; JST_B2B-XH-A; PARTREV N/A
J8: Pwm set up; JST_B3B-XH-A; PARTREV 7/4/21
J9, J10, J16: Conn_01x02_Pin; R_0402_1005Metric
J11: R LED conector; JST_B2B-XH-A; PARTREV N/A
J12, J14: G. LED conector; JST_B2B-XH-A; PARTREV N/A
J13, J15: R. LED conector; JST_B2B-XH-A; PARTREV N/A
K1, K3, K4, K5, K6: SRD-05VDC-SL-C; RELAY_SRD-05VDC-SL-C
L1, L2: MMZ2012Y152BT; INDC2012X87N
PS1: MC00100; CONV_MC00100; PARTREV NA
Q1, Q3: AOD409; DPAK
Q2, Q10: IRLR2705PBF; TO229P990X239-4N; PARTREV 1/11/05
Q5, Q6, Q7, Q8, Q9, Q11, Q12, Q13, Q14: MMBT3904; SOT-23
R1: 2,2kΩ; R_0603_1608Metric_Pad0.98x0.95mm_HandSolder
R2: 100kΩ; R_0603_1608Metric_Pad0.98x0.95mm_HandSolder
R3, R4, R5, R6, R7, R9, R10, R11, R12, R13, R14, R15, R16, R17, R18, R19, R20, R21, R25, R27, R30, R32, R38, R39, R40, R41, R44: 10kΩ; R_0603_1608Metric_Pad0.98x0.95mm_HandSolder
R8, R22, R24, R26, R28, R29, R31, R37, R42, R43: 1kΩ; R_0603_1608Metric_Pad0.98x0.95mm_HandSolder
R23: 22Ω 0.1%; R_0603_1608Metric_Pad0.98x0.95mm_HandSolder
R33, R34, R35, R36: 220Ω; R_0603_1608Metric_Pad0.98x0.95mm_HandSolder
U1: IRF5305; TO263AB
U2: ADS1115IDGS; TSSOP-10_3x3mm_P0.5mm
U3: LM317L_SO8; SOIC-8_3.9x4.9mm_P1.27mm

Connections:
+5V: A1.30 (VIN), C1.1, C2.1, C3.1, C4.1, C9.2, C10.1, D4.1 (K), D5.1 (K), D6.1 (K), D7.1 (K), D8.1 (K), J5.2, J8.3, K1.A1, K3.A1, K4.A2, K5.A2, K6.A1, L1.2, PS1.OUT+, R11.1, R13.1, R15.1, R28.2, U3.1 (VI)
+BATT: D2.1 (K), D13.1 (K), D14.1 (K), PS1.IN+, Q1.3, Q3.3, R10.1, R39.1, R40.1, R44.1, U1.2
/AMS: A1.6 (D3), R22.1
/CGS: A1.11 (D8), R24.1
/DV1I: A1.7 (D4), R33.1
/DV2I: A1.2 (D0/RX), R36.1
/GV1I: A1.8 (D5), R34.1
/GV2I: A1.1 (D1/TX), R35.1
/HBS1C: A1.12 (D9), R43.1
/HBS2C: A1.13 (D10), R42.1
/HBS2C_B: J9.1, Q13.1 (B), R41.1, R42.2
/HBS2C_E: D16.1 (K), J9.2, Q10.1, Q13.2 (E), R4.1
/HBS3C: A1.14 (D11), R37.1
/HBS4C: A1.15 (D12), J10.2, R8.1
/HBS4C_B: Q12.1 (B), R7.1, R8.2
/HBS4C_E: D15.1 (K), J10.1, Q2.1, Q12.2 (E), R3.1
/PWM_Value: A1.22 (A3), J8.2
/RGLB: A1.5 (D2), C7.1, R16.2
/RGRB: A1.21 (A2), C6.1, R14.2
/RM: J16.2, K4.COM, U2.4 (AIN0)
/RM_A0: A1.19 (A0), J16.1
/RSB: A1.20 (A1), C5.1, R12.2
/SCL: A1.24 (A5), J5.3, R19.2, U2.10 (SCL)
/SDA: A1.23 (A4), J5.4, R20.2, U2.9 (SDA)
/VDS: A1.10 (D7), R26.1
/VS1: A1.9 (D6), R29.1
/VS2: A1.16 (D13), R31.1
/Valve_1_Input_1: J3.1, K5.NC
/Valve_1_Input_2: J3.2, K6.NC
/Valve_2_Input_1: J4.1, K5.NO
/Valve_2_Input_2: J4.2, K6.NO
/Valve_IN_1: D3.1 (K), K1.NO, K3.NO, K4.NO, K5.COM, Q2.4, Q3.4
/Valve_IN_2: D3.2 (A), K6.COM, Q1.4, Q10.4
GND: A1.4 (GND), A1.29 (GND), C1.2, C2.2, C3.2, C4.2, C5.2, C6.2, C7.2, C9.1, C10.2, D15.2 (A), D16.2 (A), J1.2, J2.1, J5.1, J6.1, J7.1, J8.1, J11.1, J12.1, J13.1, J14.1, L2.2, PS1.IN-, PS1.OUT-, Q2.3, Q5.2 (E), Q6.2 (E), Q7.2 (E), Q8.2 (E), Q9.2 (E), Q10.3, Q11.2 (E), Q14.2 (E), R1.2, R2.2, R3.2, R4.2, R6.2, R7.2, R21.2, R25.2, R27.2, R30.2, R32.2, R38.2, R41.2
GND2: C8.1, L2.1, R17.2, U2.3 (GND)
unnamed: D2.2 (A), R2.1, U1.1
unnamed: D4.2 (A), K4.A1, Q5.3 (C)
unnamed: D5.2 (A), K3.A2, Q6.3 (C)
unnamed: D6.2 (A), K1.A2, Q7.3 (C)
unnamed: D7.2 (A), K5.A1, Q8.3 (C)
unnamed: D8.2 (A), K6.A2, Q9.3 (C)
unnamed: D13.2 (A), Q1.1, R5.1, R10.2
unnamed: D14.2 (A), Q3.1, R9.1, R44.2
unnamed: F1.2, J15.2, U1.3
unnamed: F1.1, J1.1
unnamed: J2.2, R11.2, R12.1
unnamed: J6.2, R13.2, R14.1
unnamed: J7.2, R15.2, R16.1
unnamed: J11.2, R33.2
unnamed: J12.2, R34.2
unnamed: J13.2, R35.2
unnamed: J14.2, R36.2
unnamed: J15.1, R1.1
unnamed: K1.COM, R28.1
unnamed: Q5.1 (B), R21.1, R22.2
unnamed: Q6.1 (B), R24.2, R25.1
unnamed: Q7.1 (B), R26.2, R27.1
unnamed: Q8.1 (B), R29.2, R30.1
unnamed: Q9.1 (B), R31.2, R32.1
unnamed: Q11.1 (B), R37.2, R38.1
unnamed: Q11.3 (C), R9.2
unnamed: Q12.3 (C), R39.2
unnamed: Q13.3 (C), R40.2
unnamed: Q14.1 (B), R6.1, R43.2
unnamed: Q14.3 (C), R5.2
unnamed: R23.1, U3.2 (VO), U3.3 (VO), U3.6 (VO), U3.7 (VO)
unnamed: R17.1, U2.1 (ADDR)
unnamed: R18.2, U2.2 (ALERT/RDY)
unnamed: K3.COM, R23.2, U3.4 (ADJ)
VDD: C8.2, L1.1, R18.1, R19.1, R20.1, U2.8 (VDD)

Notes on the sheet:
Interfaces
Voltage Divider Switch
Filtering
LED Indicators
Power supply
Valve IN Concetor
Analog Measurement Switch
Current Generator Switch
16 Bit AD Converter
Polarity switch
Valve Sequence Switch
Controller
Valves INPUTS

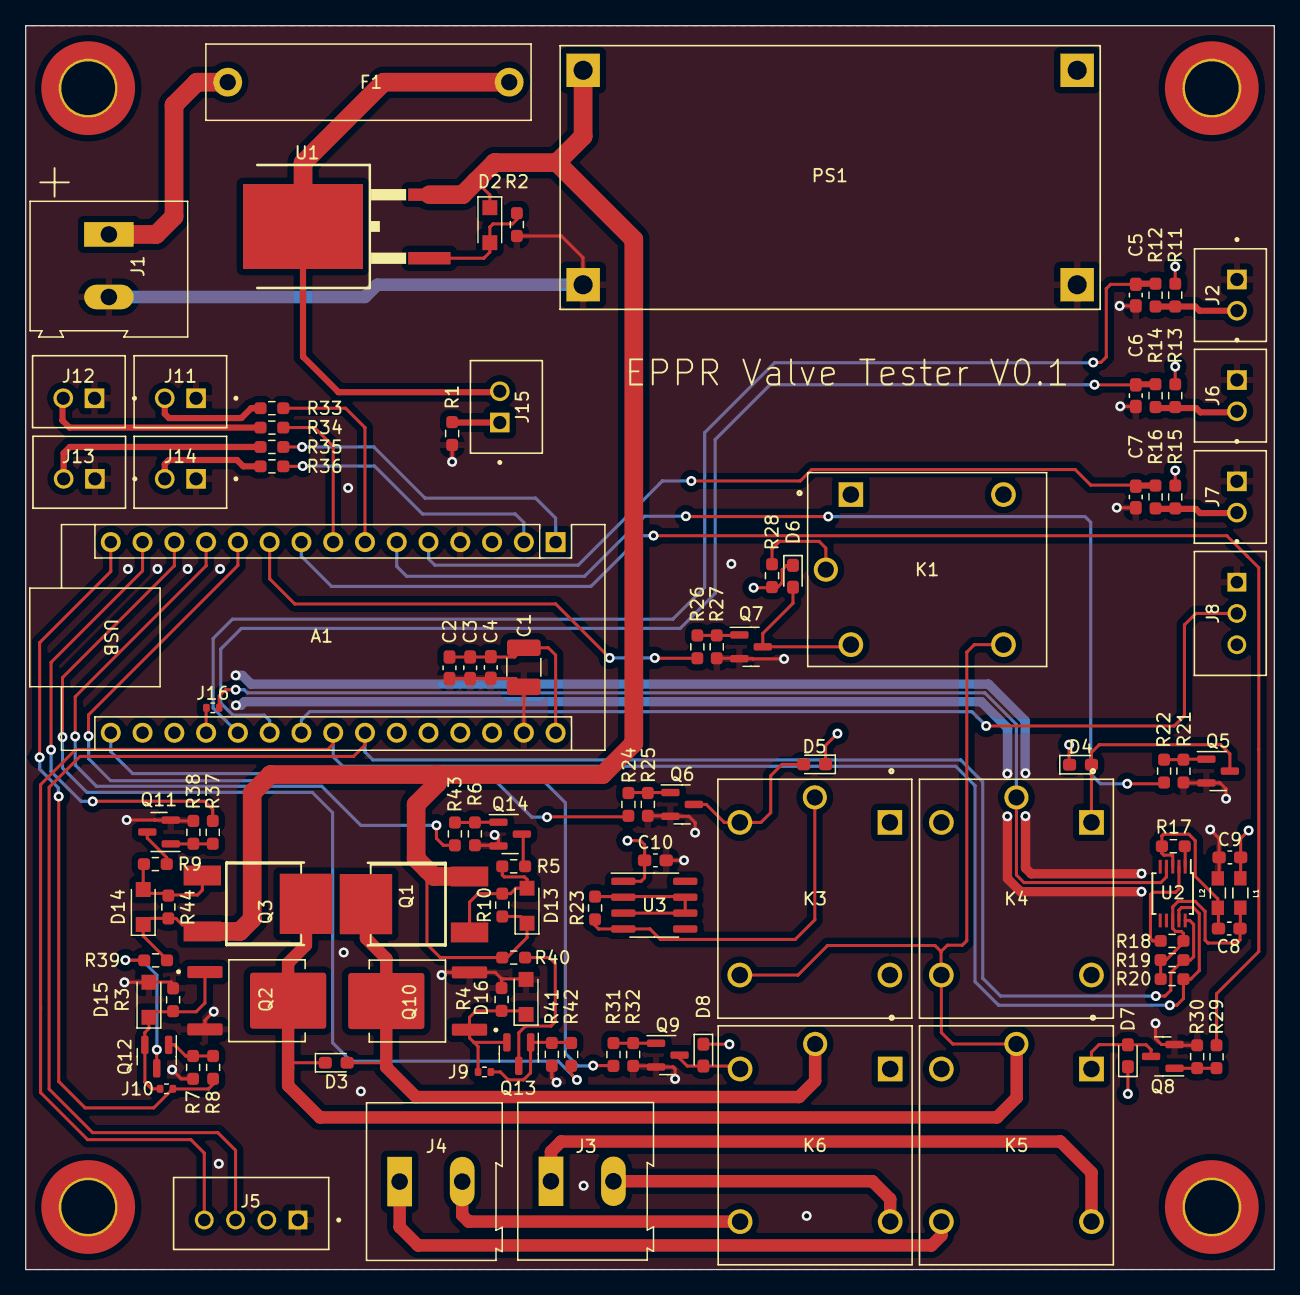
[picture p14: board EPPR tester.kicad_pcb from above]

Board: 4 copper layers, 99.8 x 99.4 mm, 107 parts (0 on the bottom side), 70 nets.

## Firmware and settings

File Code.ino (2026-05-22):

#include <Wire.h>
#include <hd44780.h>
#include <hd44780ioClass/hd44780_I2Cexp.h>
#include <avr/pgmspace.h>
#include <Adafruit_ADS1X15.h>
#include <String.h>
#include <EEPROM.h>
#include <avr/wdt.h>



#define GoRightButton A2
#define GoLeftButton 2
#define StartButton A1

#define ValveSelect1 13
#define ValveSelect2 6

#define HBS1C 9
#define HBS2C 10
#define HBS3C 11
#define HBS4C 12

#define CGS 8
#define VDS 7
#define AMS 3

enum class SystemMode : uint8_t {
  MainMenu,
  Settings,
  Testing
};

enum class MenuStates : uint8_t {
  FullTest,
  ContTest,
  OhmTest,
  FullOutTest,
  PwmTest,
  Settings 
};

enum class SettingStates : uint8_t{
  ValveNumber,
  Language,
  Save
};

enum class AppLanguage : uint8_t {
  HU = 0,
  EN = 1,
  DE = 2
};

enum TextId {
  TXT_APP_TITLE = 0,
  TXT_BOOTING,
  TXT_MENU_FULL_TEST,
  TXT_MENU_CONT_TEST,
  TXT_MENU_OHM_TEST,
  TXT_MENU_FULL_OUT_TEST,
  TXT_MENU_PWM_TEST,
  TXT_MENU_SETTINGS,
  TXT_SET_VALVE_NUM,
  TXT_SET_LANGUAGE,
  TXT_BTN_SAVE,
  TXT_SAVE_SUCCESS,
  TXT_RESTART
};

SystemMode currentMode = SystemMode::MainMenu;

Adafruit_ADS1115 ads;

const uint8_t  LanguageArrayNumber = 10;

const char langEN[][17] PROGMEM = {
    "Valve Tester",
    "Booting.",
    "1. FULL TEST",
    "2. CONT. TEST",
    "3. OHM TEST",
    "4. FULL OUT TEST",
    "5. PWM TEST",
    "6. SETTINGS",
    "Valve number: ",
    "Language: ",
    "Save",
    "Save done",
    "Restart"
};

const char langHU[][17] PROGMEM = {
    "Szelep Teszter",
    "Betoltes.",
    "1. Teljes Teszt",
    "2. Folyt. Meres",
    "3. Ell. Meres",
    "4. Kivez. Teszt",
    "5. PWM Teszt",
    "6. Beallitasok",
    "Szelep szam: ",
    "Nyelv: ",
    "Mentes",
    "Mentes Sikeres",
    "Ujrainditas"
};

const char langDE[][17] PROGMEM = {
    "Ventil Tester",    
    "Laden.",         
    "1. Volltest",     
    "2. Fortsetzen",    
    "3. Kontr. Mess.",  
    "4. Ansteuer. T.",  
    "5. PWM Test",      
    "6. Einstellungen", 
    "Ventil Nr.: ",     
    "Sprache: ",
    "Speichern",
    "Gespeichert",
    "Neustart"         
};

char textBuffer[17];

const uint8_t  FirstStartNumber = 78;
const uint8_t  FirstStartNumberAddress = 0;
const uint8_t  ValveAddress = 4;
const uint8_t  LanguageAddress = 6;

const uint8_t  MaxMenuNumber = 5;
const uint8_t  MinMenuNumber = 0;

const uint8_t  MaxSettingNumber = 2;
const uint8_t  MinSettingNumber = 0;

const uint8_t  SaveButtonNumber = 2;

const uint8_t LcdAddress = 0x27;

hd44780_I2Cexp lcd(LcdAddress);

bool SettingIndicator = false;

uint8_t  ValveNumber = 1;
String Language = "HU";

uint8_t  TemporaryValveNumber = ValveNumber;

uint8_t  MaxValveNumber = 2;
uint8_t  MinValveNumber = 1;

AppLanguage LanguageNumber = AppLanguage::HU;
AppLanguage TemporaryLanguageNumber = AppLanguage::HU;
AppLanguage MaxLanguageNumber = AppLanguage::DE;
AppLanguage MinLanguageNumber = AppLanguage::HU;

MenuStates  MenuCurrentState = MenuStates::FullTest;
MenuStates MenuLastState = static_cast<MenuStates>(255);

SettingStates  SettingCurrentState = SettingStates::ValveNumber;
SettingStates  SettingLastState = static_cast<SettingStates>(255);

uint8_t  lastGoRightButtonState = 1;
uint8_t  lastGoLeftButtonState = 1;
uint8_t  lastStartButtonState = 1;


char* getText(TextId id) {
  switch (LanguageNumber) {
    case AppLanguage::HU:
      strcpy_P(textBuffer, langHU[id]);
      break;
    case AppLanguage::EN:
      strcpy_P(textBuffer, langEN[id]);
      break;
    case AppLanguage::DE:
      strcpy_P(textBuffer, langDE[id]);
      break;
  }
  return textBuffer;
}


void lcdBooting()
{
  lcd.begin(16,4);
  lcd.backlight();

  int titleLen = strlen(getText(TXT_APP_TITLE));
  lcd.setCursor((16 - titleLen) / 2, 0); 
  lcd.print(getText(TXT_APP_TITLE));


  int bootingLen = strlen(getText(TXT_BOOTING));
  lcd.setCursor((16 - bootingLen) / 2, 1);
  lcd.print(getText(TXT_BOOTING));

  delay(1000);
  lcd.print(".");
  delay(1000);
  lcd.print(".");
  delay(1000);

  lcd.clear();
  lcd.print(getText(TXT_MENU_FULL_TEST));
}

void doFirstStart()
{
  int FirstStartReadedCheckNumber;
  EEPROM.get(FirstStartNumberAddress, FirstStartReadedCheckNumber);

  if (FirstStartReadedCheckNumber != FirstStartNumber)
  {
    EEPROM.update(ValveAddress,1);
    EEPROM.update(LanguageAddress,0);
    EEPROM.put(FirstStartNumberAddress,78);
  }
  

}

void setup() {
  Serial.begin(9600);

  ads.begin();

  pinMode(GoRightButton, INPUT);
  pinMode(GoLeftButton, INPUT);
  pinMode(StartButton, INPUT);

  pinMode(ValveSelect1, OUTPUT);
  pinMode(ValveSelect2, OUTPUT);

  pinMode(HBS1C, OUTPUT);
  pinMode(HBS2C, OUTPUT);
  pinMode(HBS3C, OUTPUT);
  pinMode(HBS4C, OUTPUT);

  pinMode(CGS,OUTPUT);
  pinMode(VDS,OUTPUT);
  pinMode(AMS,OUTPUT);

// EZT ki kell majd venni

  digitalWrite(HBS1C, LOW);
  digitalWrite(HBS2C, LOW);
  digitalWrite(HBS3C, LOW);
  digitalWrite(HBS4C, LOW);

  digitalWrite(CGS, LOW);
  digitalWrite(VDS, LOW);
  digitalWrite(AMS, LOW);

//------------------
  doFirstStart();
  
  EEPROM.get(ValveAddress, ValveNumber);
  TemporaryValveNumber = ValveNumber;
  Serial.println(TemporaryValveNumber);

  uint8_t buffer;
  EEPROM.get(LanguageAddress, buffer); 
  Serial.println(buffer);

  LanguageNumber = static_cast<AppLanguage>(buffer);
  TemporaryLanguageNumber = static_cast<AppLanguage>(buffer);
  lcdBooting();
}

void DetectRightButton(void)
{
  if(digitalRead(GoRightButton) == 0 && lastGoRightButtonState == 1)
  {
    switch(currentMode)
    {
      case SystemMode::MainMenu:
      { 
        uint8_t nextIndex = static_cast<uint8_t>(MenuCurrentState) + 1;

        if (nextIndex > static_cast<uint8_t>(MenuStates::Settings))
        {
          nextIndex = static_cast<uint8_t>(MenuStates::FullTest);
        }

        MenuCurrentState = static_cast<MenuStates>(nextIndex);
        break;
      } 

      case SystemMode::Settings:
      { 
        uint8_t nextIdx = static_cast<uint8_t>(SettingCurrentState) + 1;
        if (nextIdx > static_cast<uint8_t>(SettingStates::Save)) {
            nextIdx = static_cast<uint8_t>(SettingStates::ValveNumber);
          }
        SettingCurrentState = static_cast<SettingStates>(nextIdx);
        break;
      } 
      
      case SystemMode::Testing:
        break;
    }   
  }

  lastGoRightButtonState = digitalRead(GoRightButton);
}

void DetectLeftButton(void)
{
  if(digitalRead(GoLeftButton) == 0 && lastGoLeftButtonState == 1)
  {
    switch(currentMode)
    {
      case SystemMode::MainMenu:
      { 
        uint8_t prevIndex = static_cast<uint8_t>(MenuCurrentState);
        if (prevIndex == 0)
        {
          prevIndex = static_cast<uint8_t>(MenuStates::Settings);
        }
        else
        {
          prevIndex--;
        }

        MenuCurrentState = static_cast<MenuStates>(prevIndex);
        break;
      } 

      case SystemMode::Settings:
      { 
        uint8_t prevIdx = static_cast<uint8_t>(SettingCurrentState);
        if (prevIdx == 0) {
          prevIdx = static_cast<uint8_t>(SettingStates::Save);
        } else {
          prevIdx--;
        }
        SettingCurrentState = static_cast<SettingStates>(prevIdx);
        break;
      }
    }
  }
  lastGoLeftButtonState = digitalRead(GoLeftButton);
}

void softwareReset() {
  wdt_enable(WDTO_15MS);
  while (1) {

  }
}

void ChangeMenu(void)
{

  if (MenuCurrentState != MenuLastState)
  {
    lcd.clear();

    switch (MenuCurrentState)
    {
      case MenuStates::FullTest:
        lcd.print(getText(TXT_MENU_FULL_TEST));
        break;

      case MenuStates::ContTest:
        lcd.print(getText(TXT_MENU_CONT_TEST));
        break;

      case MenuStates::OhmTest:
        lcd.print(getText(TXT_MENU_OHM_TEST));
        break;

      case MenuStates::FullOutTest:
        lcd.print(getText(TXT_MENU_FULL_OUT_TEST));
        break;

      case MenuStates::PwmTest:
        lcd.print(getText(TXT_MENU_PWM_TEST));
        break;

      case MenuStates::Settings:
        lcd.print(getText(TXT_MENU_SETTINGS));
        break;
    } 
    MenuLastState = MenuCurrentState;
  }
}

void setValve1()
{
  digitalWrite(ValveSelect1, HIGH);
  digitalWrite(ValveSelect2, HIGH);
}

void setValve2()
{
  digitalWrite(ValveSelect1, LOW);
  digitalWrite(ValveSelect2, LOW);
}

void connectCG()
{
  digitalWrite(CGS, HIGH);
}

void disconnectCG()
{
  digitalWrite(CGS, LOW);
}

void connectVD()
{
  digitalWrite(VDS, HIGH);
}

void disconnectVD()
{
  digitalWrite(VDS, LOW);
}

void connectAM()
{
  digitalWrite(AMS, HIGH);
}

void disconnectAM()
{
  digitalWrite(AMS, LOW);
}


void DetectStartButton()
{
  if (digitalRead(StartButton) == 0 && lastStartButtonState == 1)
  { 
    switch(currentMode)
    {
      case SystemMode::MainMenu:
        if (MenuCurrentState == MenuStates::Settings)
        {
          currentMode = SystemMode::Settings;
          SettingCurrentState = SettingStates::ValveNumber; 
          SettingLastState = static_cast<SettingStates>(255);
        }
        else
        {
          currentMode = SystemMode::Testing;
        }
        break; 

      case SystemMode::Settings:
        switch(SettingCurrentState)
        {
          case SettingStates::ValveNumber:
            TemporaryValveNumber++;
            if (TemporaryValveNumber > MaxValveNumber) {
              TemporaryValveNumber = MinValveNumber;
            }
            SettingLastState = static_cast<SettingStates>(255); 
            break;

          case SettingStates::Language:
            {
              uint8_t nextLang = static_cast<uint8_t>(TemporaryLanguageNumber) + 1;
              
              if (nextLang > static_cast<uint8_t>(MaxLanguageNumber)) {
                nextLang = static_cast<uint8_t>(MinLanguageNumber);
              }
              
              TemporaryLanguageNumber = static_cast<AppLanguage>(nextLang);
            }
            break;

          case SettingStates::Save:
            EEPROM.update(ValveAddress, TemporaryValveNumber);
            EEPROM.update(LanguageAddress, static_cast<uint8_t>(TemporaryLanguageNumber));
            
            displaySaveSuccess();
            
            softwareReset(); 
            break;
        }
        break;
        
      case SystemMode::Testing:
        break;
    }
  }
  lastStartButtonState = digitalRead(StartButton);
}

int getColForBlinking()
{
  switch(SettingCurrentState)
  {
    case SettingStates::ValveNumber:
      return strlen(getText(TXT_SET_VALVE_NUM));; // HU: "Szelep szam: "
      break;

    case SettingStates::Language:
      return strlen(getText(TXT_SET_LANGUAGE));
      break;

    case SettingStates::Save:
      return 0;
  }
  return 0;
}

int getRowForBlinking()
{
  switch(SettingCurrentState)
  {
    case SettingStates::ValveNumber: return 1;
    case SettingStates::Language:    return 2;
    case SettingStates::Save:        return 3;
  }
  return 0;
}

String getDataForBlinking()
{
  switch(SettingCurrentState)
  {
    case SettingStates::ValveNumber:
      return String(TemporaryValveNumber);

    case SettingStates::Language:
      switch(TemporaryLanguageNumber)
      {
        case AppLanguage::HU: return "HU";
        case AppLanguage::EN: return "EN";
        case AppLanguage::DE: return "DE";
      }
      break;

    case SettingStates::Save:
      return getText(TXT_BTN_SAVE);
  }
  return "";
}

void displaySaveSuccess()
{
  lcd.clear();
  
  switch(LanguageNumber) {
    case AppLanguage::HU: lcd.setCursor(1,0); break;
    case AppLanguage::EN: lcd.setCursor(3,0); break;
    case AppLanguage::DE: lcd.setCursor(3,0); break;
  }
  lcd.print(getText(TXT_SAVE_SUCCESS));

  switch(LanguageNumber) {
    case AppLanguage::HU: lcd.setCursor(1,1); break;
    case AppLanguage::EN: lcd.setCursor(3,1); break;
    case AppLanguage::DE: lcd.setCursor(3,1); break;
  }
  lcd.print(getText(TXT_RESTART));

  delay(1000);
  lcd.print(".");
  delay(1000);
  lcd.print(".");
  delay(1000);
  lcd.print(".");
}

void blinkText(int col, int row, String text) {
  static unsigned long previousTime = 0;
  static bool isVisible = true;
  
  static int lastCol = -1;
  static int lastRow = -1;
  static String lastText = "";
  
  const long blinkInterval = 500;
  unsigned long currentTime = millis();

  if (col != lastCol || row != lastRow || text != lastText) {
    
    if (lastCol != -1 && lastRow != -1) {
      lcd.setCursor(lastCol, lastRow);
      lcd.print(lastText);
    }

    isVisible = true;          
    previousTime = currentTime; 
    lastCol = col;
    lastRow = row;
    lastText = text;
  } 
  else if (currentTime - previousTime >= blinkInterval) {
    previousTime = currentTime;
    isVisible = !isVisible;
  }

  lcd.setCursor(col, row);
  if (isVisible) {
    lcd.print(text);
  } else {
    int len = text.length();
    for (int i = 0; i < len; i++) {
      lcd.print(" ");
    }
  }
}

void blinkText(int col, int row, int number) {
  blinkText(col, row, String(number));
}


void printCentered(const char* text, int row) {
  int len = strlen(text);
  if (len > 16) len = 16;
  int pos = (16 - len) / 2;
  

  lcd.setCursor(0, row);
  lcd.print("                "); 
  
  lcd.setCursor(pos, row);
  lcd.print(text);
}

void printCentered(float value, int precision, int row) {
  char buffer[17]; 
  dtostrf(value, 1, precision, buffer); 
  printCentered(buffer, row); 
}


void drawSettingsMenu() {
  if (SettingCurrentState != SettingLastState) {
    lcd.clear();
  
    lcd.print(getText(TXT_MENU_SETTINGS)); 

    lcd.setCursor(0, 1);
    lcd.print(getText(TXT_SET_VALVE_NUM));

    if (SettingCurrentState != SettingStates::ValveNumber) {
      lcd.print(TemporaryValveNumber);
    }


    lcd.setCursor(0, 2);
    lcd.print(getText(TXT_SET_LANGUAGE));

    if (SettingCurrentState != SettingStates::Language) {
      switch(TemporaryLanguageNumber) {
        case AppLanguage::HU: lcd.print("HU"); break;
        case AppLanguage::EN: lcd.print("EN"); break;
        case AppLanguage::DE: lcd.print("DE"); break;
      }
    }

    lcd.setCursor(0, 3);
    if (SettingCurrentState != SettingStates::Save) {
      lcd.print(getText(TXT_BTN_SAVE));
    }

    SettingLastState = SettingCurrentState;
  }

  blinkText(getColForBlinking(), getRowForBlinking(), getDataForBlinking());
}

float getAveragedVoltage(float multipler) {
  int32_t sum = 0;
  const int numReadings = 100;

  for (int i = 0; i < numReadings; i++) {
    sum += ads.readADC_SingleEnded(0);
    delay(2);
  }

  float averageRaw = (float)sum / numReadings;

  float voltage = (averageRaw * multipler) / 1000.0;

  if (voltage >= 0.5) {
    return -1.0; 
  }

  return voltage;
}

float calculateVDResistance(float measuredVoltage) {
  float U_be = 5.0;  
  float R1 = 1000.0; 

  float resistance = R1 * (measuredVoltage / (U_be - measuredVoltage));

  return resistance;
}

float calculateCGResistance(float measuredVoltage) {

  const float contsCurrent = 0.056818;
  float resistance = measuredVoltage / contsCurrent;

  return resistance;
}



void FullOutTest()
{
  lcd.clear();
  printCentered(getText(TXT_MENU_FULL_OUT_TEST), 0);
  
  // Alapértelmezett kezdőállapot
  printCentered("KI", 1);
  digitalWrite(HBS2C, LOW);
  digitalWrite(HBS3C, LOW);

  while(digitalRead(StartButton) == 0) { delay(10); }
  delay(50); 

  bool exitTest = false; 
  
  uint8_t localLastLeft = 1;
  uint8_t localLastRight = 1;

  while(!exitTest)
  {

    uint8_t currentLeft = digitalRead(GoLeftButton);
    if (currentLeft == 0 && localLastLeft == 1)
    {
      printCentered("KI", 1);
      digitalWrite(HBS2C, LOW);
      digitalWrite(HBS3C, LOW);
      
      delay(50); 
    }
    localLastLeft = currentLeft;


    uint8_t currentRight = digitalRead(GoRightButton);
    if (currentRight == 0 && localLastRight == 1)
    {
      printCentered("BE", 1);
      digitalWrite(HBS2C, HIGH);
      digitalWrite(HBS3C, HIGH);
      
      delay(50);
    }
    localLastRight = currentRight;

    if (digitalRead(StartButton) == 0)
    {
      exitTest = true;
      delay(50);
    }
  }

  printCentered("Teszt Vege", 1);
  printCentered("Kilepes", 2);
  delay(1000);
  digitalWrite(HBS2C, LOW);
  digitalWrite(HBS3C, LOW);

  while(digitalRead(StartButton) == 0) { delay(10); }
  delay(50);

  lastStartButtonState = 1; 
  lastGoLeftButtonState = 1;
  lastGoRightButtonState = 1;
}
void ContTest()
{
  if (ValveNumber == 1)
  {
    ads.setGain(GAIN_EIGHT);

    connectVD();
    connectAM();
    digitalWrite(HBS2C, HIGH);

    float voltage = getAveragedVoltage(0.015625);
    
    if (voltage != -1)
    {
      printCentered("Folytonos",1);
      printCentered("<100 Ohm",2);
    }

    else
    {
      printCentered("Szakadt",1);
      printCentered(">100 Ohm",2);
    }

    
    disconnectVD();
    disconnectAM();
    digitalWrite(HBS2C, LOW);
  }

}

void OhmTest()
{
  if (ValveNumber == 1)
  {
    ads.setGain(GAIN_EIGHT);

    connectVD();
    connectAM();
    digitalWrite(HBS2C, HIGH);

    float voltage = getAveragedVoltage(0.015625);
    if (voltage != -1)
    {
      float resisntace = calculateVDResistance(voltage);

      if (resisntace > 29)
      {
      lcd.setCursor(0,2);
      printCentered((String(resisntace,2) + " Ohm").c_str(), 2);
      }
      else
      {
        disconnectVD();
        connectCG();
        ads.setGain(GAIN_TWO);
        voltage = getAveragedVoltage(0.0625);
        resisntace = calculateCGResistance(voltage);

        if (resisntace > 15)
        {
          lcd.setCursor(0,2);
          printCentered((String(resisntace,2) + " Ohm").c_str(), 2);
        }
        else
        {
          ads.setGain(GAIN_FOUR);
          voltage = getAveragedVoltage(0.03125);
          resisntace = calculateCGResistance(voltage);

          if (resisntace > 7)
          {
            lcd.setCursor(0,2);
            printCentered((String(resisntace,2) + " Ohm").c_str(), 2);
          }

          else
          {
            ads.setGain(GAIN_EIGHT);
            voltage = getAveragedVoltage(0.015625);
            resisntace = calculateCGResistance(voltage);
            lcd.setCursor(0,2);
            printCentered((String(resisntace,2) + " Ohm").c_str(), 2);
          }
        }
      }
      
    }
    else
    {
      printCentered("Szakadt",1);
      printCentered(">100 Ohm",2);
    }

    disconnectVD();
    disconnectCG();
    digitalWrite(HBS2C, LOW);
  }



}


void loop() {

  DetectRightButton();
  DetectLeftButton();
  DetectStartButton();

  switch(currentMode) {
    case SystemMode::MainMenu:
       ChangeMenu();
       break;

    case SystemMode::Settings:
       drawSettingsMenu();
       break;

    case SystemMode::Testing:
      switch(MenuCurrentState) {
        case MenuStates::FullTest:
          lcd.print("hello");
          delay(4000);
          MenuLastState = static_cast<MenuStates>(255);
          currentMode = SystemMode::MainMenu;
          break;
        case MenuStates::ContTest:
          ContTest();
          delay(4000);
          MenuLastState = static_cast<MenuStates>(255);
          currentMode = SystemMode::MainMenu;
          break;
        case MenuStates::OhmTest:
          OhmTest();
          delay(4000);
          MenuLastState = static_cast<MenuStates>(255);
          currentMode = SystemMode::MainMenu;
          break;
        case MenuStates::FullOutTest:
          FullOutTest();
          MenuLastState = static_cast<MenuStates>(255);
          currentMode = SystemMode::MainMenu;
          break;
        case MenuStates::PwmTest:

          MenuLastState = static_cast<MenuStates>(255);
          currentMode = SystemMode::MainMenu;
          break;
        default:
           break;
       }
       break;
  }
}

  

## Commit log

2026-05-23 Add hardware components section to README
    Added hardware components section detailing reliability, cost-effectiveness, and industrial compliance. Included specific components like Arduino Nano, LCD display, ADS1115, and LM317.
2026-05-23 Add schematic and PCB design section to README
    Added section for schematic and PCB design details.
2026-05-23 Fix image link for schematic in README
2026-05-23 Revise README with detailed circuit and power supply info
    Updated the README to include detailed circuit structure and improved clarity on power supply protection.
